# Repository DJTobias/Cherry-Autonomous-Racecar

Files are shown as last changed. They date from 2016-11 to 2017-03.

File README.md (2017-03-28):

# Cherry Autonomous Racecar (CAR) <br/>NCAT ECE Senior Design Project

## [Article on JetsonHacks](http://www.jetsonhacks.com/2017/03/02/daniel-tobias-car-cherry-autonomous-racecar/)

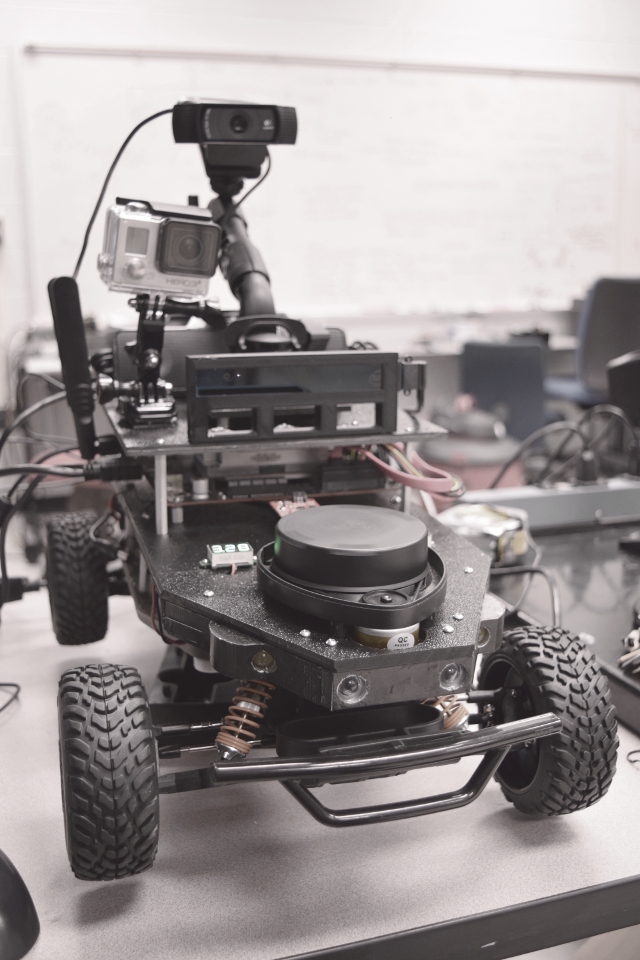
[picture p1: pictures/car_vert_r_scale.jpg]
Front view Front View CAR

<br/>

### Trial run
Trial run CAR (https://youtu.be/x3ub8OhKxhM)
<br/>

### Tear down
Tear down of CAR (https://youtu.be/HHdqdwMvcN8)
## [Hardware Schematic](/hardware/CAR_hardware_design.pdf)

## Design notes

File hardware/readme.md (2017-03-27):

# Bill of Materials
## https://goo.gl/QgxjAT
# Circuit Design
## [Teensy ESC & steering servo design](/pictures/CAR_Teensy_ESC_Steering_1Board_bb.png)
## [Neato-XV11 LIDAR power design](/pictures/Neato_Lidar_Circuit_bb.png)

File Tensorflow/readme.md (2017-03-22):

### Tensorflow implementaion of the CNN from End to End Learning for Self-Driving Car
Sample Dataset
<br/>
https://drive.google.com/drive/folders/0Bx1XHaRXk3kSUGZuVnJfaWJiY2M?usp=sharing

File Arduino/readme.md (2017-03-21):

# Arduino code for the Teensy 3.6 microcontroller
## On host PC
### Setup Arduino 
https://www.arduino.cc/en/Guide/Linux
<br/>
https://www.arduino.cc/download_handler.php?f=/arduino-1.8.1-linux64.tar.xz
<br/>

### Setup Teensyduino 
https://www.pjrc.com/teensy/td_download.html
<br/>
Save the text in the link below as a file named "49-teensy.rules"
<br/>
https://www.pjrc.com/teensy/49-teensy.rules
<br/>
sudo cp 49-teensy.rules /etc/udev/rules.d/

### Install ROS Kinetic packages and ros_lib
sudo apt-get install ros-kinetic-rosserial-arduino ros-kinetic-rosserial -y
<br/>
<br/>
**If there is a ros_lib in the arduino /sketchbook/libraries delete it**
<br/>
**Remake the ros_lib library**
<br/>
rosrun rosserial_arduino make_libraries.py ~/sketchbook/libraries
<br/>
<br/>
Find ArduinoHardware.h in ros_lib edit **line 44** to add support for Teensy 3.5 & 3.6
<br/>
\#if defined(\_\_MK20DX128\_\_) || defined(\_\_MK20DX256\_\_) || defined(\_\_MK64FX512\_\_) || defined(\_\_MK66FX1M0\_\_)
<br/>
https://github.com/ros-drivers/rosserial/blob/jade-devel/rosserial_arduino/src/ros_lib/ArduinoHardware.h

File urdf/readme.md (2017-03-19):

## Cherry Autonomous Racecar URDF

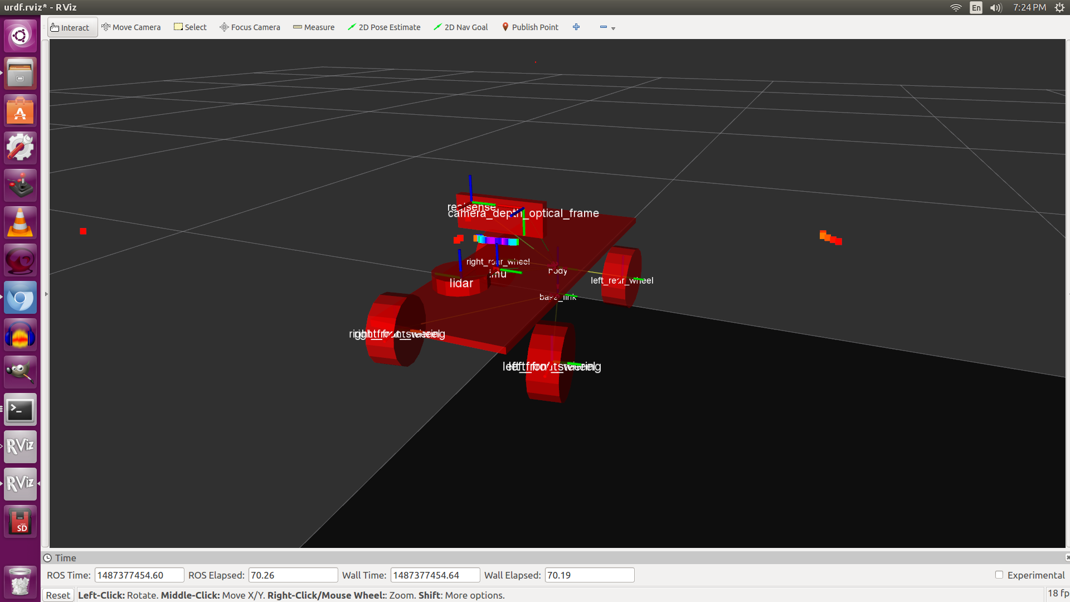
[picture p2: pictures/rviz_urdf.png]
Title


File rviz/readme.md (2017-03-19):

## Saved configuration for RVIZ to view CAR urdf and some sensors
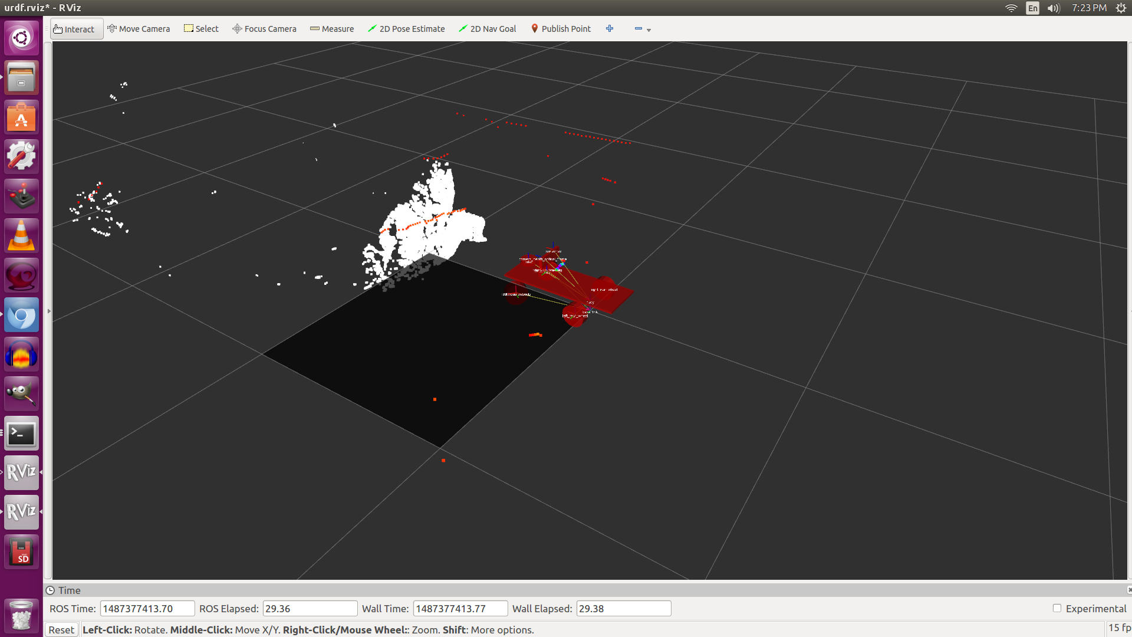
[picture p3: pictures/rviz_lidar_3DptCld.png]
Title


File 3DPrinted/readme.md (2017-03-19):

## 3D printed parts and platform schematics for the Cherry Autonomous Racecar

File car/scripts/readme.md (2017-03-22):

### Trained TF models should be place in this location

### You will have to make the folders for dataRecorder.py

cd
<br/>
mkdir DepthIMG
<br/>
mkdir TrainingIMG
<br/>
mkdir LidarIMG

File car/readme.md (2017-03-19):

## Cherry Autonomous Racecar(CAR) ROS package

### Sample trained model can be found here
https://drive.google.com/drive/folders/0Bx1XHaRXk3kSY1pfaW9hOVU4RWc
<br/>
Copy all three files into the scripts folder of the CAR ROS package
<br/>
### To start ROS Network
roslaunch car runCAR.launch
<br/>
### To start Neural Net
rosrun car runModel.py
___
## CAR controls for Xbox 360

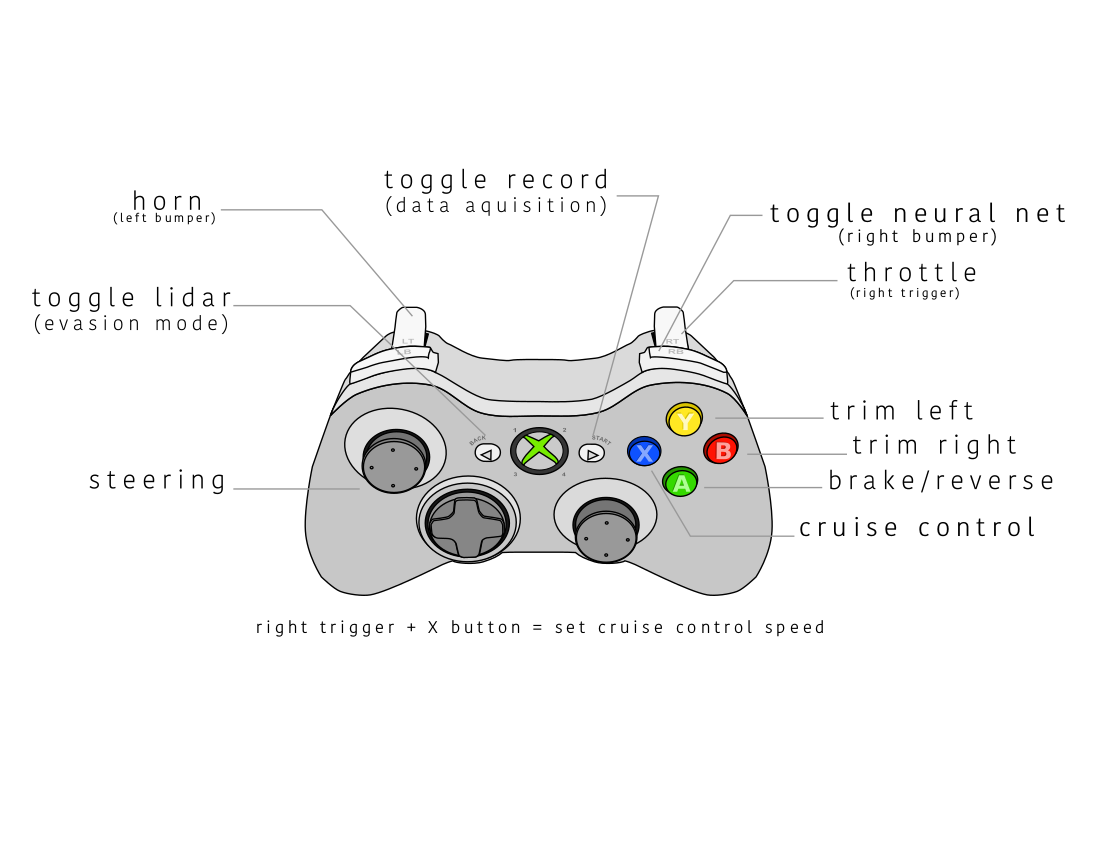
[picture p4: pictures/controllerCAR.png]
CAR Controller


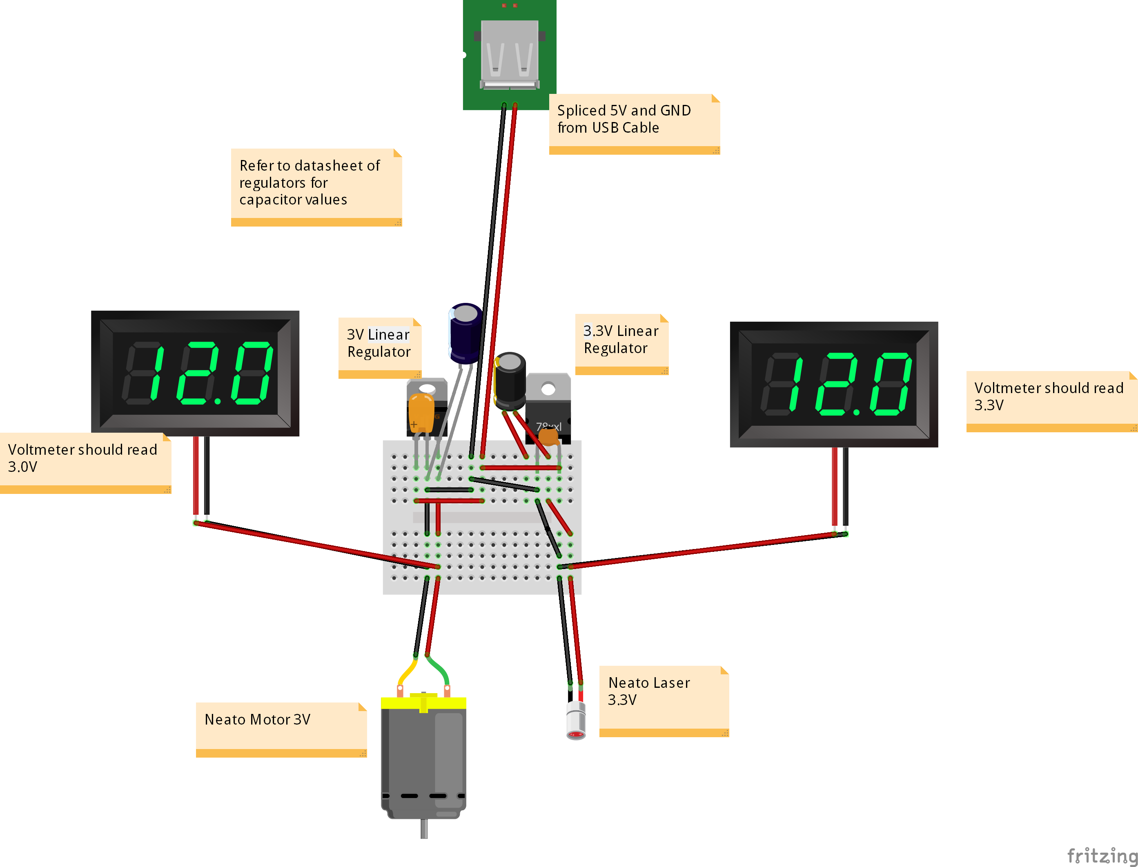
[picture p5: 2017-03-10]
pictures/Neato_Lidar_Circuit_bb.png

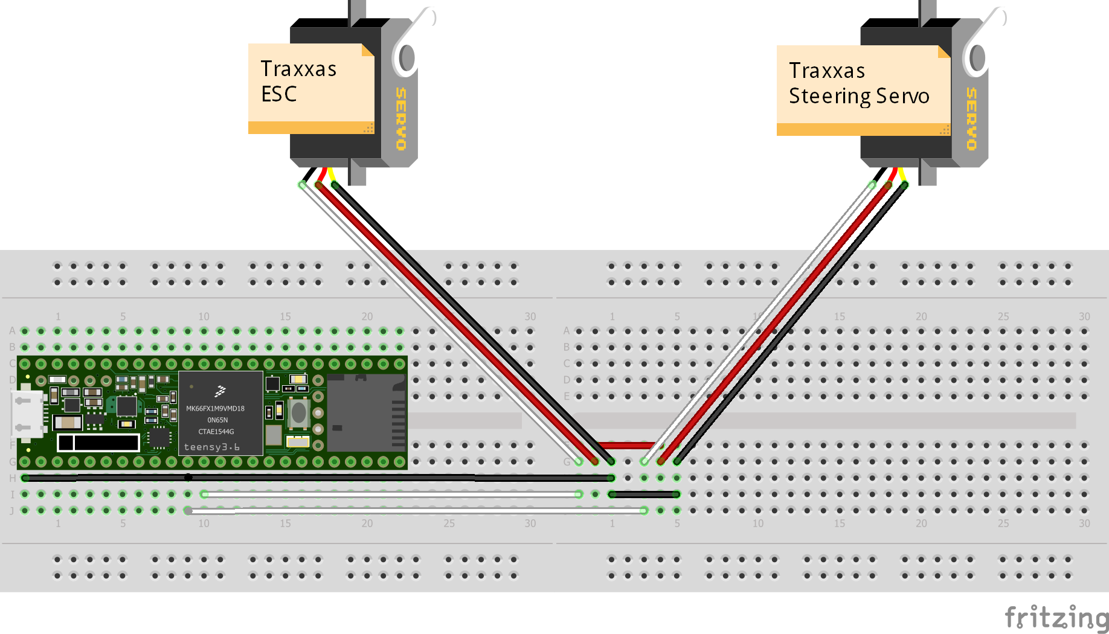
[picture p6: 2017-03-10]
pictures/CAR_Teensy_ESC_Steering_2Board_bb.png

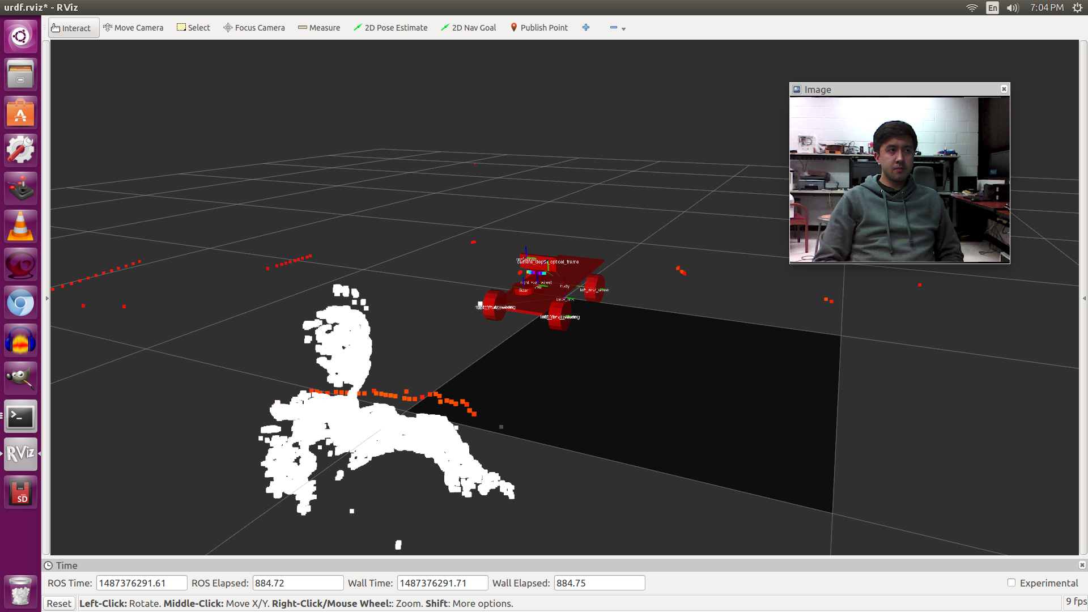
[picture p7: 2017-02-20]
pictures/rviz_lidar_3DptCld_RGB.png

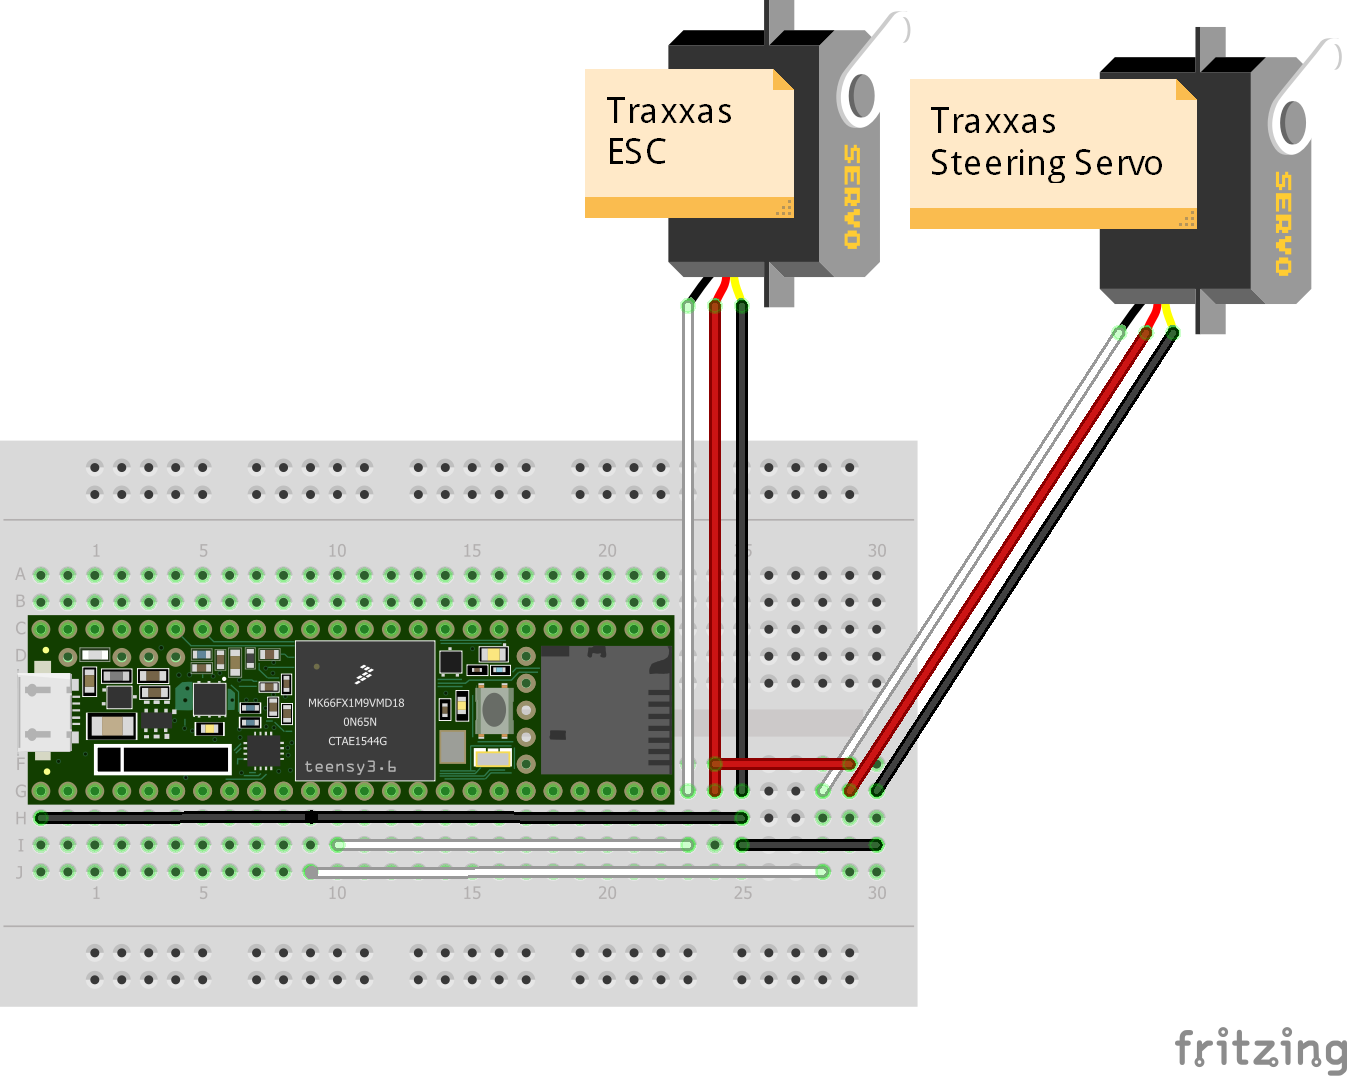
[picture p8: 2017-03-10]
pictures/CAR_Teensy_ESC_Steering_1Board_bb.png

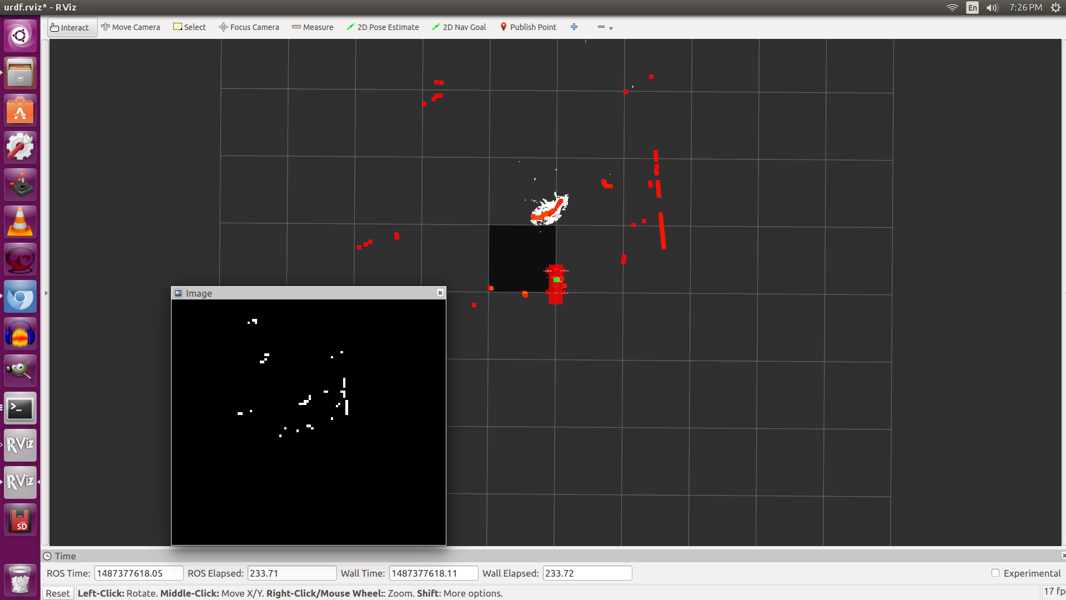
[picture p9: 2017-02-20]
pictures/rviz_lidar_lidargrid_img.png

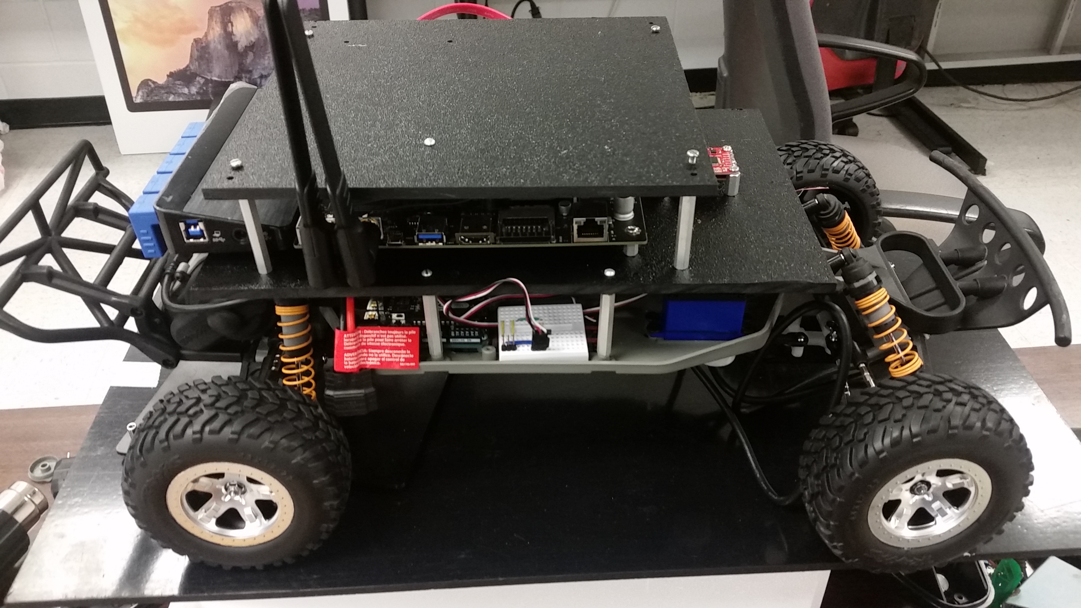
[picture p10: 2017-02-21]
pictures/car_prototype_august.jpg

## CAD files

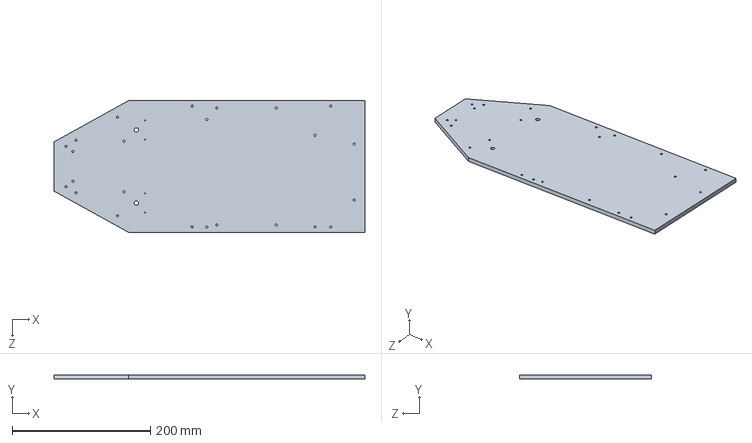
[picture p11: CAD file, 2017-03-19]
3DPrinted/car_main_platform.SLDPRT
449.3 x 6.35 x 190.5 mm

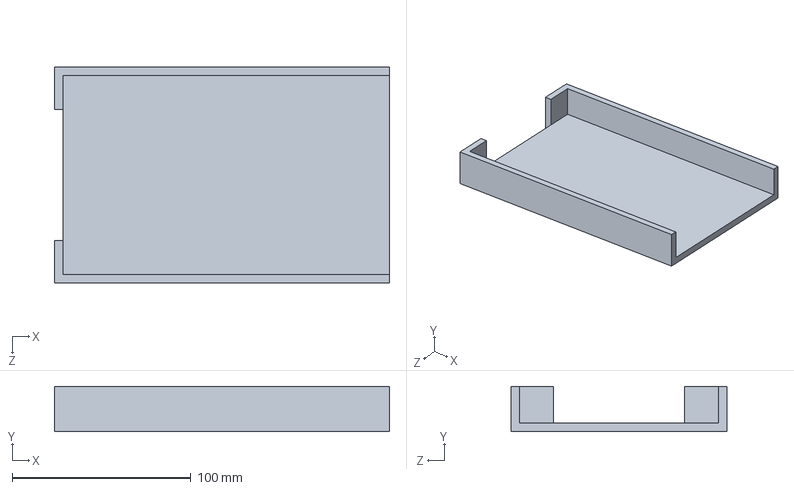
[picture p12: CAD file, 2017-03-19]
3DPrinted/car_XP18000_battery_holder.SLDPRT
187.3 x 25.4 x 120.7 mm

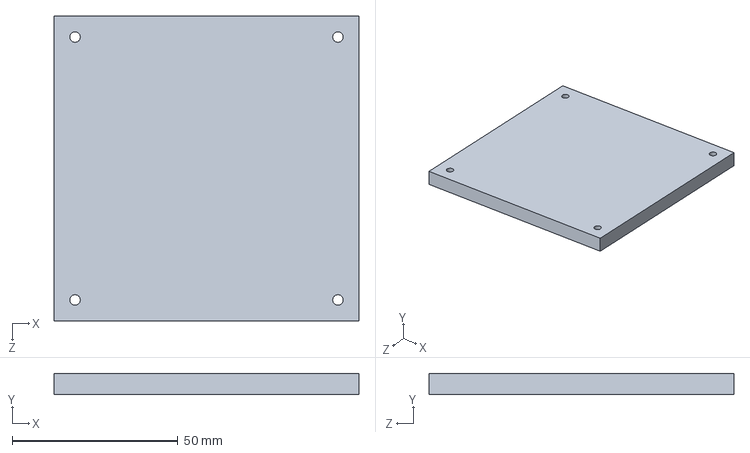
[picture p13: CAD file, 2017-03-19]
3DPrinted/car_webcam_panel.SLDPRT
92.0 x 6.35 x 92.0 mm

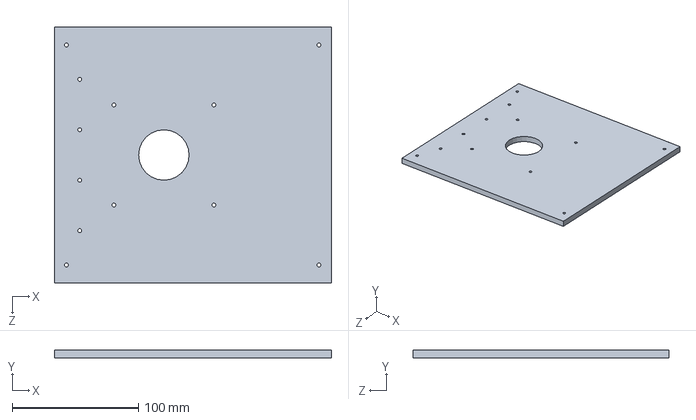
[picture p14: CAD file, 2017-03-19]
3DPrinted/car_top_panel.SLDPRT
219.7 x 6.35 x 203.2 mm

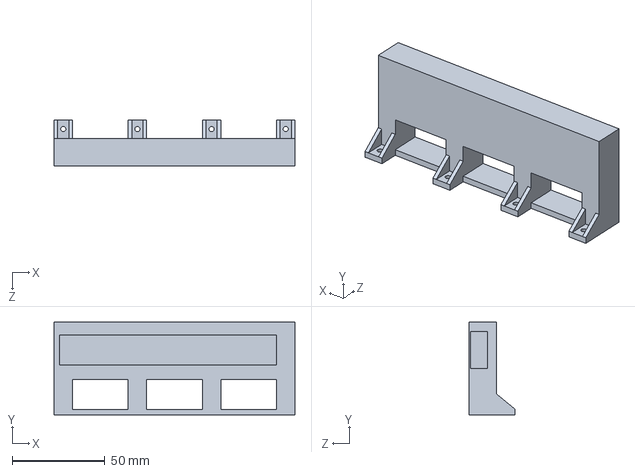
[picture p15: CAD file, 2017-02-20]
3DPrinted/car_RealSenseR200_mount.SLDPRT
130.0 x 50.0 x 25.0 mm

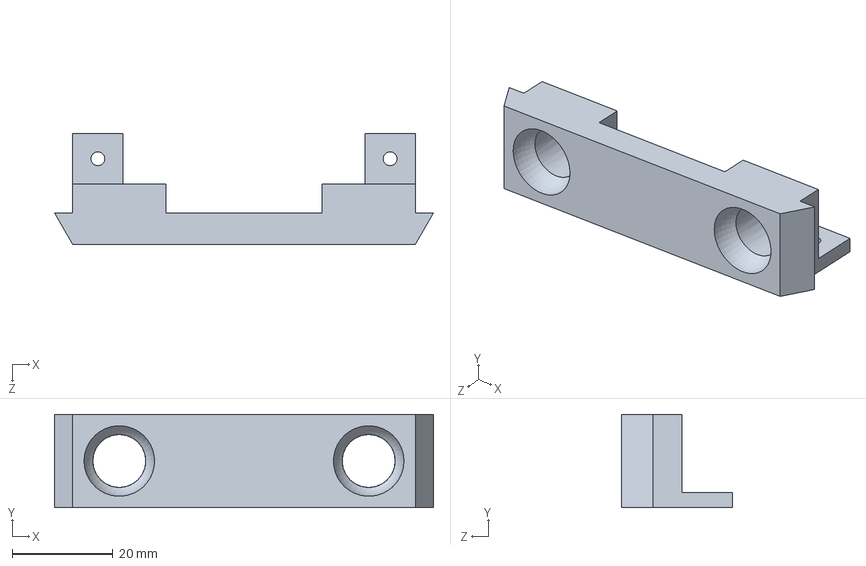
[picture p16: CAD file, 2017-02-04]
3DPrinted/car_front_headlights.SLDPRT
75.2 x 18.5 x 22.0 mm

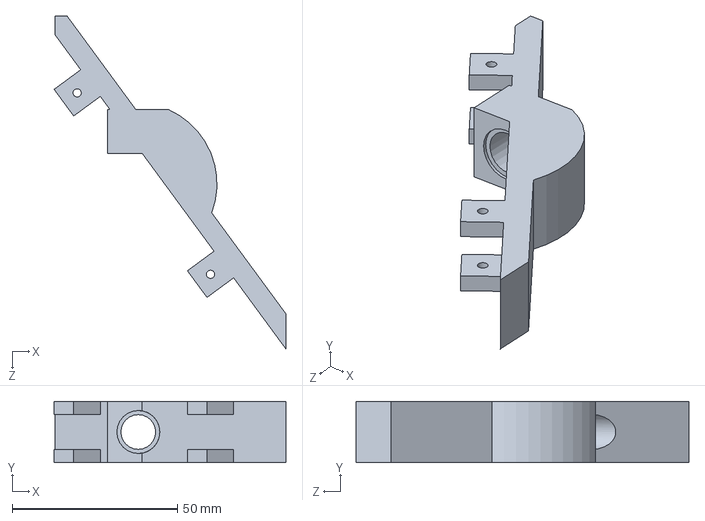
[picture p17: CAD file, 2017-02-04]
3DPrinted/car_side_turnsignal.SLDPRT
70.1 x 18.5 x 100.7 mm

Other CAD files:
3DPrinted/car_RealSenseR200_mount.STL
3DPrinted/car_XP18000_battery_holder.STL
3DPrinted/car_front_headlights.STL
3DPrinted/car_main_platform.STL
3DPrinted/car_side_turnsignal.STL
3DPrinted/car_top_panel.STL
3DPrinted/car_webcam_panel.STL

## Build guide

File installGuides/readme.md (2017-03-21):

## Install Order for Jetson TX1
1. Flash Jetpack on Jetson TX1
2. Preinstall script on Jetson TX1
3. installRealSenseR200 install to Jetson TX1
4. installJetPackSSD to install the filesystem on to the SSD
5. Preinstall script on SSD Jetpack
6. installRealSenseR200 install to SSD Jetpack (for safe measure)
7. installKernelModulesToSSD
8. installROS install to SSD Jetpack
9. Install CAR ROS package and dependencies
10. Follow steps in installRealSenseR200ROS install to SSD Jetpack
11. Follow steps in installXV_11  install to SSD Jetpack
12. Create swapspace from createSwap
13. Follow steps in installTensorFlowCUDA for SSD Jetpack
14. Follow steps in installTensorFlow for SSD Jetpack
15. (Optional) compile OpenCV 3.1 with CUDA and Gtreamer support from source
<br/>

## Install order Host PC
1. installROS_HOSTPC
2. installCUDA_cuDNN_HOSTPC
3. installTensorFlow_HOSTPC

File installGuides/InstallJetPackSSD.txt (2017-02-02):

###Tested with clean flash of Jetpack 2.2.1 on TX1
###Tested with Intel SSD 730
###Tested on 8/4/2016
###Tested with Tegra210_Linux_R24.1.0_armhf.tbz2
###Tested with Tegra_Linux_Sample-Root-Filesystem_R24.1.0_armhf.tbz2

##Tested on 1/14/2017 
##Tested with Samsung Evo 750 120GB SSD
##Tested with Tegra210_Linux_R24.2.1_aarch64.tbz2
##Tested with Tegra_Linux_Sample-Root-Filesystem_R24.2.1_aarch64.tbz2

###This process was done on a Lenovo Thinkpad with a ultrabay expansion for an extra SSD as seen here http://a.co/ctPOGup

###Done on HOST PC go to
https://developer.nvidia.com/embedded/linux-tegra
###download latest version .
download Jetson TX1 64-bit Driver Package
download 64-bit Sample Root Filesystem
move both to home directory.

###Extracts files and moves the sample filesystem to rootfs keeps permissions.  Do not use GUI extract

sudo tar -vxjf TegraXXX_Linux_RXX.X.X_armhf.tbz2
cd Linux_for_Tegra/rootfs
sudo tar jxpf ../../Tegra_Linux_Sample-Root-Filesystem_RXX.X.X_armhf.tbz2

###Run the apply_binaries.sh script to copy the NVIDIA libraries into rootfs directory.

cd ..
sudo ./apply_binaries.sh

###Format target storage to ext4 and mount it.
###use lsblk to make sure you are formatting the correct drive in my case only two storage devices are present on host

sudo mkfs.ext4 /dev/sdb
sudo mkdir /mnt/jetson
sudo mount /dev/sd? /mnt/jetson

###Copy Sample file system to target storage and unmount it.

cd Linux_for_Tegra/rootfs
sudo cp -a * /mnt/jetson && sync
sudo umount /mnt/jetson

###Turn on JetsonTX1 with previous clean installation of jetpack.
###Tested with clean install of Jetpack 2.2.1

sudo nautilus

###navigate to /boot/extlinux
###locate extlinux.conf
###open with gedit
###locate argument "root=/dev/mmcblk0p1" or something similar to this near the end
###change to "root=/dev/sda"  
###sda assumes that there are no other partitions on the SSD
###save file

###I deleted the ~extlinux.conf generated by gedit for safe measure
###it can be found by using the ls command in /boot/extlinux directory
sudo rm extlinux.conf~
###Turn off TX1

sudo shutdown -h now

###Make sure that there are no other storage devices except the SSD connected
###Turn on TX1 it should boot as SSD as home and show the internal eMMC as a SDCard on the unity launcher

###Steps derived from
http://demotomohiro.github.io/hardware/jetson_tk1/setup/nvidia_kernel.html
http://demotomohiro.github.io/hardware/jetson_tk1/setup/external_storage.html
https://devtalk.nvidia.com/default/topic/794002/-solved-l4t21-1-problem-booting-from-sata/#4386318

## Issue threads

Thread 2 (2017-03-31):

How to set up Teeny on Jetson TX1

dat-ai, 2017-03-31:
Dear Tobias,

I wonder how you could install Teensy on Jetson TX1. I am trying to do the same, however, Teensy 3.2 does not support AARCH 64 architecture yet..

Thanks!!

VisualMicro, 2017-03-31:
I think you install Teensy software on the Teensy then both the gpu and the teensy communicate using Serial tx/rx

dat-ai, 2017-03-31:
Good point. Thank you @VisualMacro! I will look into this option.

I previously set up Teensy communicate via a USB port

DJTobias, 2017-03-31:
Hey Dat,

A while back I could never get the Arduino IDE to work on the Jetson TX1, so I decided to upload the .ino files from the host computer instead.

dat-ai, 2017-03-31:
Thanks Tobias. I wrote my Teensy code on a Window machine, too.

However, my issue is that the Jetson TX1 does not recognize Teensy as `/dev/ttyACM*` or `/dev/ttyUSB*`  when I plug it in.

Did you install any extra packages or drivers for Teensy to work on TX1

DJTobias, 2017-03-31:
I see,

I don't think I install anything else to get it to work, maybe try this on the TX1
https://www.arduino.cc/en/Guide/Linux#toc6

Try attaching a regular Arduino to see if can recognize it.
It also might be a USB hub issue I am not sure what you are using.

I am assuming you can see the board on your host computer which is windows based from your post above, but have you tried it on a version of Ubuntu on your host to see if it can read the port?

dat-ai, 2017-03-31:
Finally, it worked!

The issue is because someone disabled `CONFIG_USB_ACM` kernel module on the NVIDIA Jetson( I actually used NVIDA Jetson TX2, Ubuntu 16.04, kernel-4-4.15)

Steps to resolve the issue:

1. Follow this tutorial: http://www.jetsonhacks.com/2017/03/25/build-kernel-and-modules-nvidia-jetson-tx2/
2. Before actually make kernel.  Run this command
```
sudo sed -i 's/.*CONFIG_USB_ACM.*/# CONFIG_USB_ACM=y/' /usr/src/kernel/kernel-4.4/.config
```
3. Follow the rest of the tutorial

At the end `dmesg` should show this when plugging in the Teensy
```
[  125.602321] usb 1-2.4: USB disconnect, device number 5
[  166.518422] usb 1-2.2: new full-speed USB device number 6 using xhci-tegra
[  166.627754] usb 1-2.2: New USB device found, idVendor=16c0, idProduct=0483
[  166.634715] usb 1-2.2: New USB device strings: Mfr=1, Product=2, SerialNumber=3
[  166.642213] usb 1-2.2: Product: USB Serial
[  166.646492] usb 1-2.2: Manufacturer: Teensyduino
[  166.651192] usb 1-2.2: SerialNumber: 2481500
**[  166.657388] cdc_acm 1-2.2:1.0: ttyACM0: USB ACM device**
```

Closed 2017-03-31.

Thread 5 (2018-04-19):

Training CNN

ArtlyStyles, 2018-04-19:
Could you please explain how to collect the steering angle and throttle during the manual driving for training? Is there special API supported by the hardware?

tevenfeng, 2018-08-31:
During the manual driving you have to use your joystick to control the car, and the joystick should be able to give you the steering angle and throttle could be obtained if you set a global maximum speed manually. That's how I get these parameters.

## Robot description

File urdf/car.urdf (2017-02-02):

<?xml version="1.0"?>
<robot name="car">

  <link name="base_link">
    <visual>
      <geometry>
        <box size =".001 .001 .001"/>
      </geometry>
      <origin rpy="0 0 0" xyz="0 0 0"/>
    </visual>
  </link>

  <joint name="base_link_to_right_front_steering" type="revolute">
    <parent link="base_link"/>
    <child link="right_front_steering"/>
    <origin xyz="0.326 -0.125 0.054"/>
    <axis xyz="0 0 1"/>
    <limit lower="-0.87" upper="0.87" effort="1000" velocity="1000"/>
  </joint>

  <link name="right_front_steering">
    <visual>
      <geometry>
        <box size =".001 .001 .001"/>
      </geometry>
      <origin rpy="0 0 0" xyz="0 0 0"/>
    </visual>
  </link>

  <joint name="right_front_steering_to_right_front_wheel" type="continuous">
    <parent link="right_front_steering"/>
    <child link="right_front_wheel"/>
    <origin xyz="0.0 0.0 0.0"/>
    <axis xyz="0 1 0"/>
  </joint>

  <link name="right_front_wheel">
    <visual>
      <geometry>
        <cylinder length ="0.043" radius="0.054"/>
      </geometry>
      <origin rpy="1.57075 0 0" xyz="0 0 0"/>
    </visual>
  </link>

  <joint name="base_link_to_left_front_steering" type="revolute">
    <parent link="base_link"/>
    <child link="left_front_steering"/>
    <origin xyz="0.326 0.125 0.054"/>
    <axis xyz="0 0 1"/>
    <limit lower="-0.87" upper="0.87" effort="1000" velocity="1000"/>
  </joint>

  <link name="left_front_steering">
    <visual>
      <geometry>
        <box size =".001 .001 .001"/>
      </geometry>
      <origin rpy="0 0 0" xyz="0 0 0"/>
    </visual>
  </link>

  <joint name="left_front_steering_to_left_front_wheel" type="continuous">
    <parent link="left_front_steering"/>
    <child link="left_front_wheel"/>
    <origin xyz="0.0 0.0 0.0"/>
    <axis xyz="0 1 0"/>
  </joint>

  <link name="left_front_wheel">
    <visual>
      <geometry>
        <cylinder length ="0.043" radius="0.054"/>
      </geometry>
      <origin rpy="1.57075 0 0" xyz="0 0 0"/>
    </visual>
  </link>

  <joint name="base_link_to_body" type="revolute">
    <parent link="base_link"/>
    <child link="body"/>
    <origin xyz="0 0 0.054"/>
    <axis xyz="0 1 0"/>
    <limit lower="-0.065" upper="0.065" effort="1000" velocity="1000"/>
  </joint>

  <link name="body">
    <visual>
      <geometry>
        <box size ="0.58 0.2 0.01"/>
      </geometry>
      <origin rpy="0 0 0" xyz="0.12 0 0.054"/>
    </visual>
  </link>

  <joint name="body_to_right_rear_wheel" type="continuous">
    <parent link="body"/>
    <child link="right_rear_wheel"/>
    <origin xyz="0 -0.125 0.0"/>
    <axis xyz="0 1 0"/>
  </joint>

  <link name="right_rear_wheel">
    <visual>
      <geometry>
        <cylinder length ="0.043" radius="0.054"/>
      </geometry>
      <origin rpy="1.57075 0 0" xyz="0 0 0"/>
    </visual>
  </link>

  <joint name="body_to_left_rear_wheel" type="continuous">
    <parent link="body"/>
    <child link="left_rear_wheel"/>
    <origin xyz="0 0.125 0.0"/>
    <axis xyz="0 1 0"/>
  </joint>

  <link name="left_rear_wheel">
    <visual>
      <geometry>
        <cylinder length ="0.043" radius="0.054"/>
      </geometry>
      <origin rpy="1.57075 0 0" xyz="0 0 0"/>
    </visual>
  </link>

  <joint name="body_to_imu" type="fixed">
    <parent link="body"/>
    <child link="imu"/>
    <origin xyz="0.236 0 0.082"/>
  </joint>

  <link name="imu">
    <visual>
      <geometry>
        <box size =".01 .01 .01"/>
      </geometry>
      <origin rpy="0 0 0" xyz="0 0 0"/>
    </visual>
  </link>

  <joint name="body_to_lidar" type="fixed">
    <parent link="body"/>
    <child link="lidar"/>
    <origin xyz="0.339 0 0.107" rpy="0 0 3.1415926"/>
  </joint>

  <link name="lidar">
    <visual>
      <geometry>
        <cylinder length ="0.020" radius="0.039"/>
      </geometry>
      <origin rpy="0 0 0" xyz="0 0 0"/>
    </visual>
  </link>

  <joint name="body_to_realsense" type="fixed">
    <parent link="body"/>
    <child link="realsense"/>
    <origin xyz="0.226 -0.044 0.177"/>
  </joint>
 <!--   <origin xyz="0.226 -0.044 0.177"/>-->
  <link name="realsense">
    <visual>
      <geometry>
        <box size ="0.015 0.139 0.051"/>
      </geometry>
      <origin rpy="0 0 0" xyz="-0.0075 0.044 -0.016"/>
    </visual>
  </link>

  <joint name="body_to_camera_depth_optical_frame" type="revolute">
    <parent link="body"/>
    <child link="camera_depth_optical_frame"/>
    <origin xyz="0.226 0.04 0.177" rpy="-1.57079 0 -1.57079"/>
    <axis xyz="0 0 1"/>
    <limit lower="-0.001" upper="0.001" effort="1000" velocity="1000"/>
  </joint>

  <!-- rpy="-1.57079 1.57079 0" -->

  <link name="camera_depth_optical_frame">
    <visual>
      <geometry>
        <box size =".001 .001 .001"/>
      </geometry>
      <origin rpy="0 0 0" xyz="0 0 0"/>
    </visual>
  </link>

</robot>

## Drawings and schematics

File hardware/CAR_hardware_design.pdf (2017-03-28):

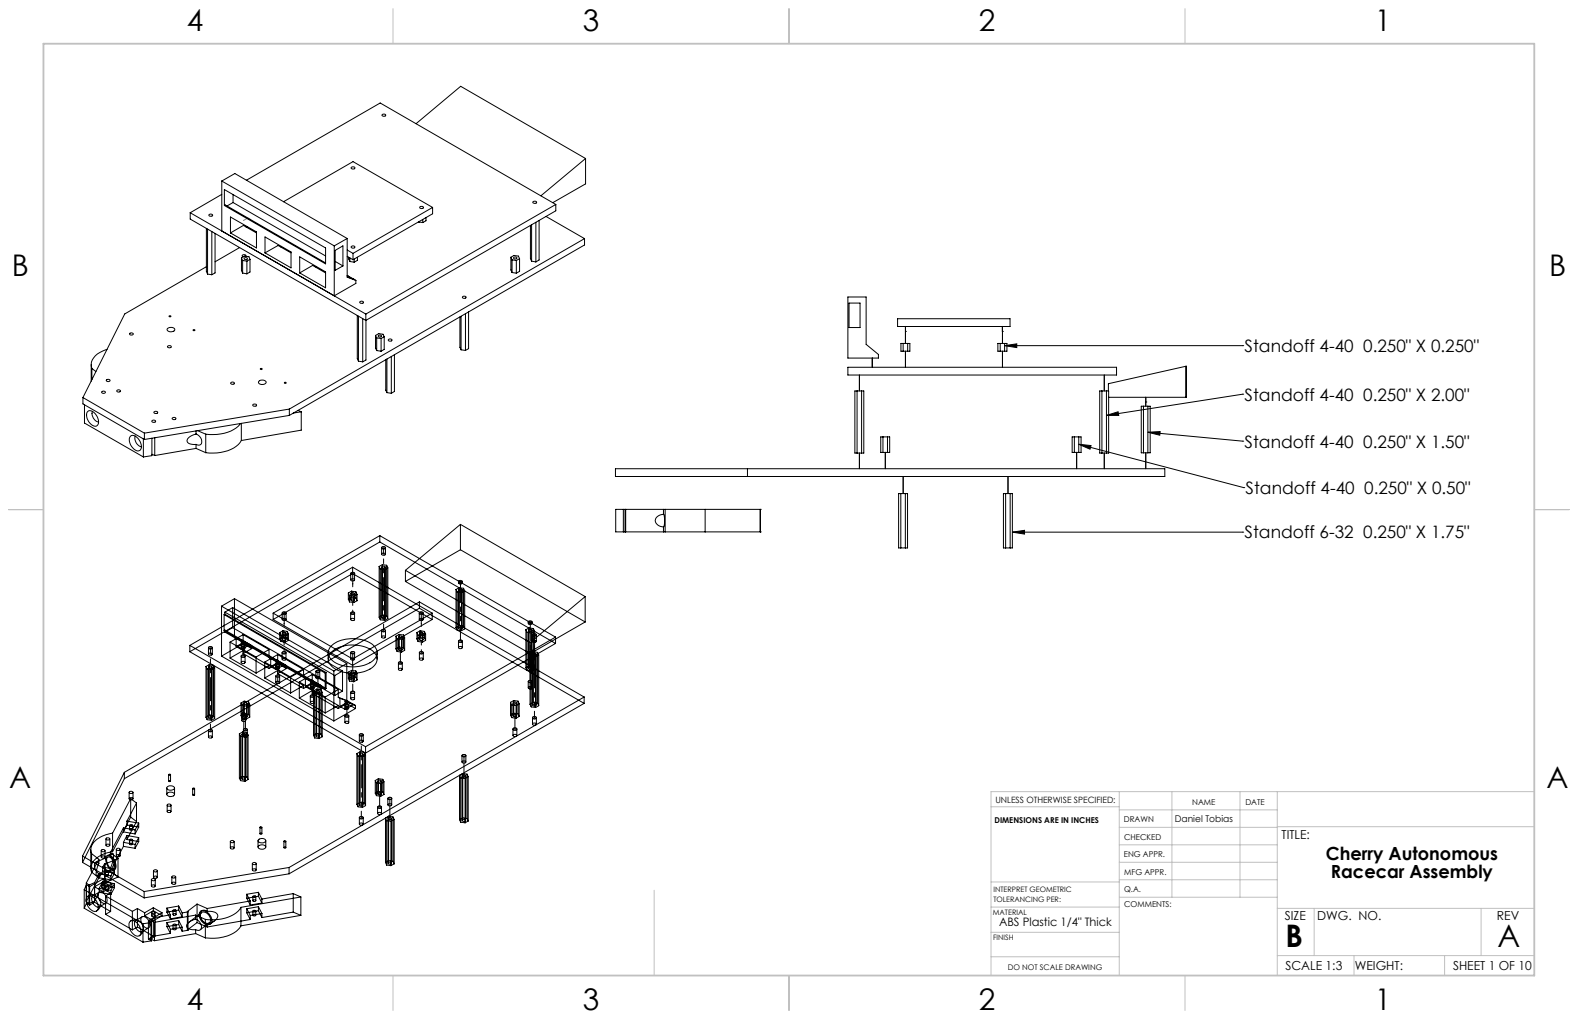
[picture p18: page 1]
Standoff 4-40 0.250" X 1.50"; Standoff 4-40 0.250" X 2.00"; Standoff 4-40 0.250" X 0.250"; Standoff 4-40 0.250" X 0.50"; Standoff 6-32 0.250" X 1.75"; DO NOT SCALE DRAWING; SHEET 1 OF 10; SCALE 1:3; WEIGHT:; DWG. NO.; REV

UNLESS OTHERWISE SPECIFIED: | | NAME | DATE
DIMENSIONS ARE IN INCHES | DRAWN | Daniel Tobias

CHECKED | | | TITLE: Cherry Autonomous Racecar Assembly

ENG APPR.
MFG APPR.

INTERPRET GEOMETRIC TOLERANCING PER: | Q.A.

MATERIAL
ABS Plastic 1/4" Thick
FINISH

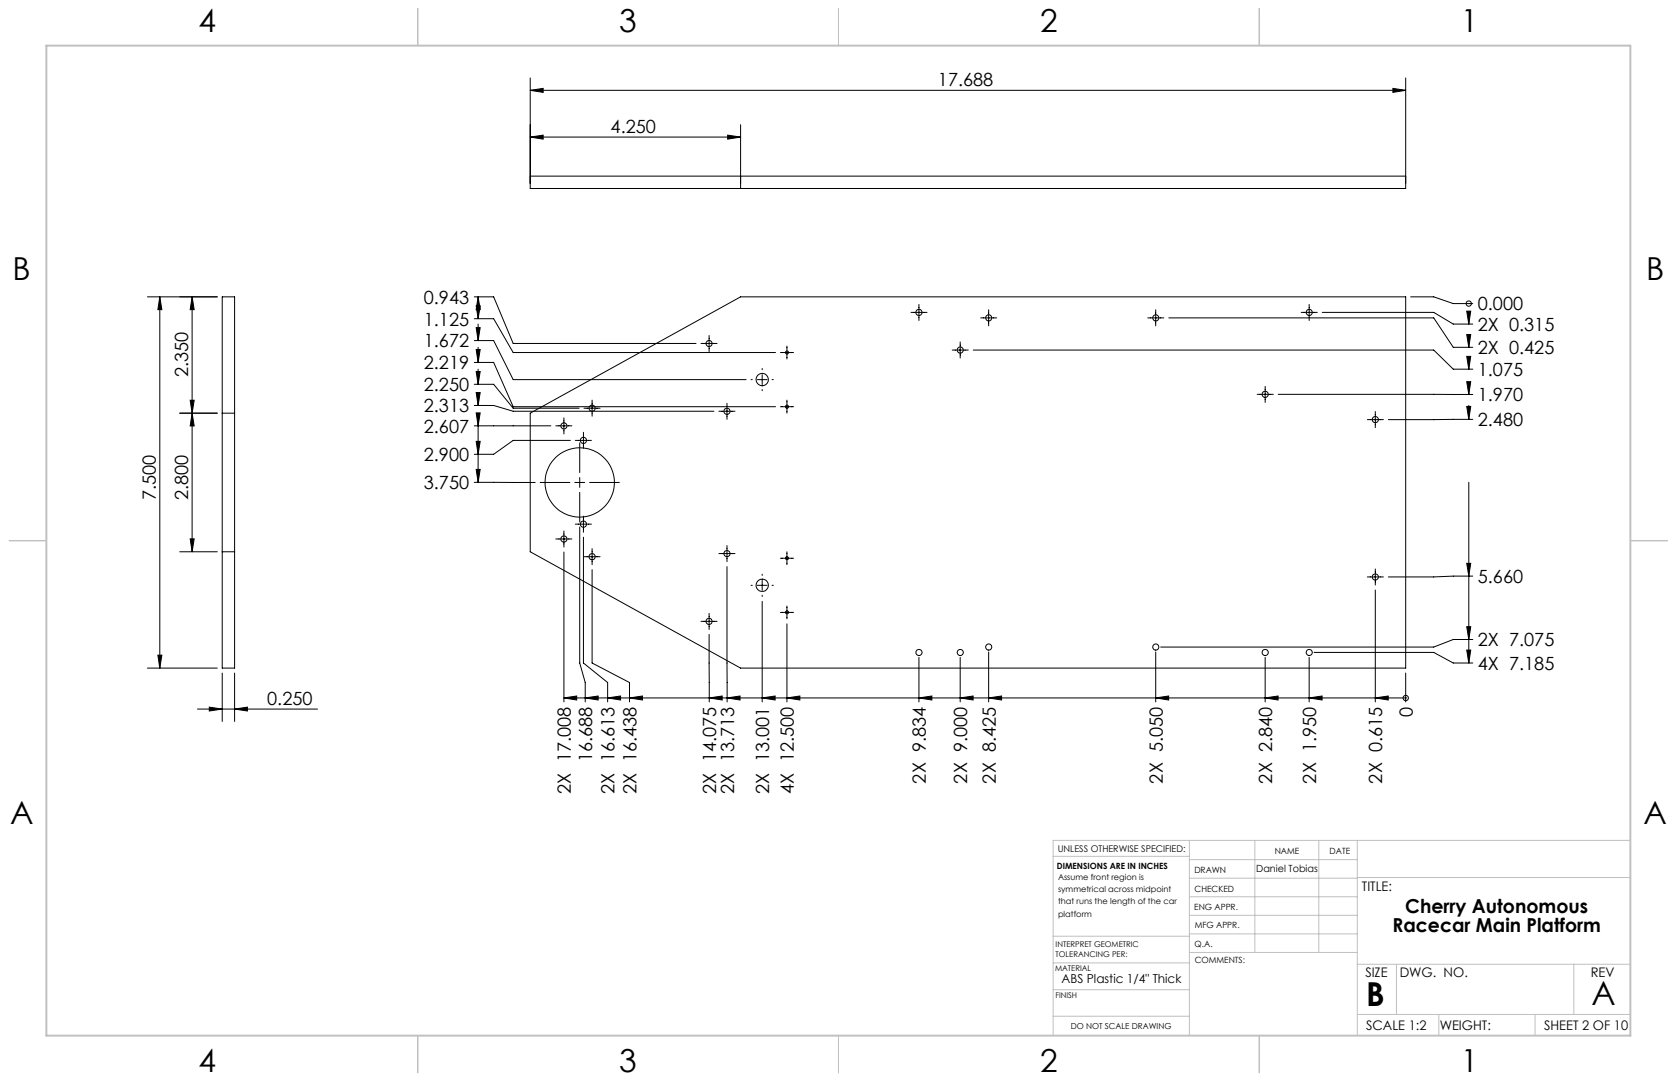
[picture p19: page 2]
SCALE 1:2; WEIGHT:; DWG. NO.; REV

UNLESS OTHERWISE SPECIFIED: | | NAME | DATE
DIMENSIONS ARE IN INCHES Assume front region is symmetrical across midpoint that runs the length of the car platform | DRAWN | Daniel Tobias

CHECKED | | | TITLE: Cherry Autonomous Racecar Main PlatformA

ENG APPR.
MFG APPR.

INTERPRET GEOMETRIC TOLERANCING PER: | Q.A.

MATERIAL
ABS Plastic 1/4" Thick

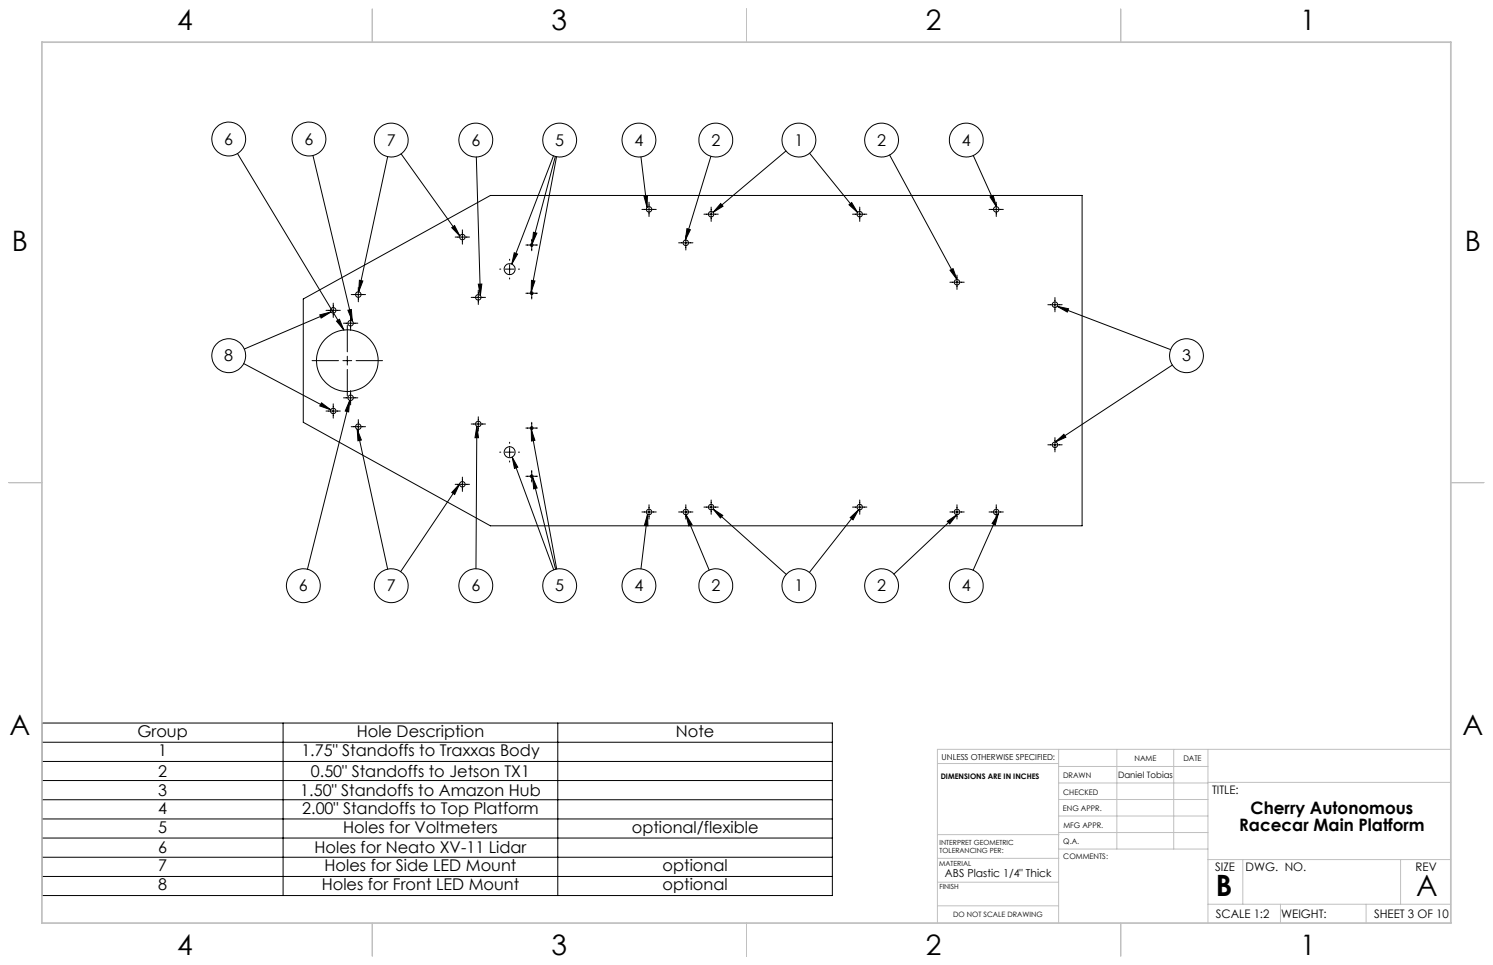
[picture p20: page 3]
0.50" Standoffs to Jetson TX1; 1.50" Standoffs to Amazon Hub; 2.00" Standoffs to Top Platform; Holes for Voltmeters; optional/flexible; Holes for Side LED Mount; optional; Holes for Front LED Mount; Daniel Tobias; SCALE 1:2; WEIGHT:; DWG. NO.; REV; MFG APPR.; ENG APPR.

Group | Hole Description | Note
1 | 1.75" Standoffs to Traxxas Body

UNLESS OTHERWISE SPECIFIED: | NAME | DATE

DIMENSIONS ARE IN INCHES

TITLE:
Cherry Autonomous
Racecar Main Platform

6 | Holes for Neato XV-11 Lidar

INTERPRET GEOMETRIC TOLERANCING PER: | Q.A.

MATERIAL
ABS Plastic 1/4" Thick

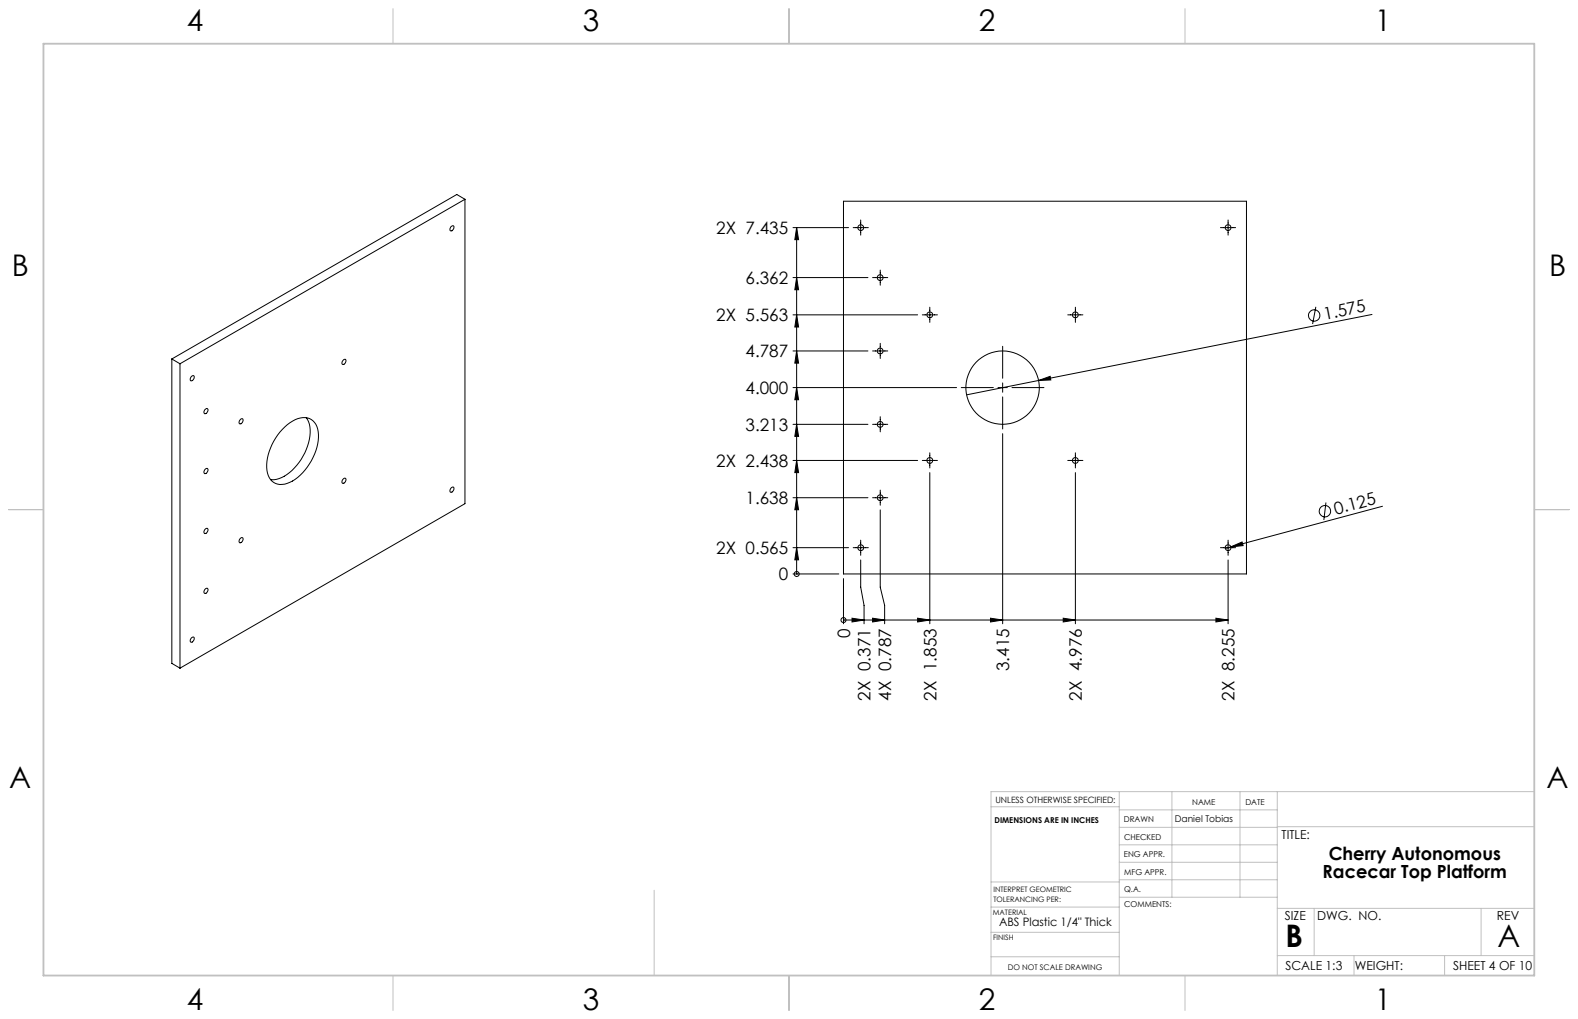
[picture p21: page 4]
SCALE 1:3; WEIGHT:; DWG. NO.; REV

UNLESS OTHERWISE SPECIFIED: | | NAME | DATE
DIMENSIONS ARE IN INCHES | DRAWN | Daniel Tobias

CHECKED | | | TITLE: Cherry Autonomous Racecar Top Platform

ENG APPR.
MFG APPR.

INTERPRET GEOMETRIC TOLERANCING PER: | Q.A.

MATERIAL
ABS Plastic 1/4" Thick

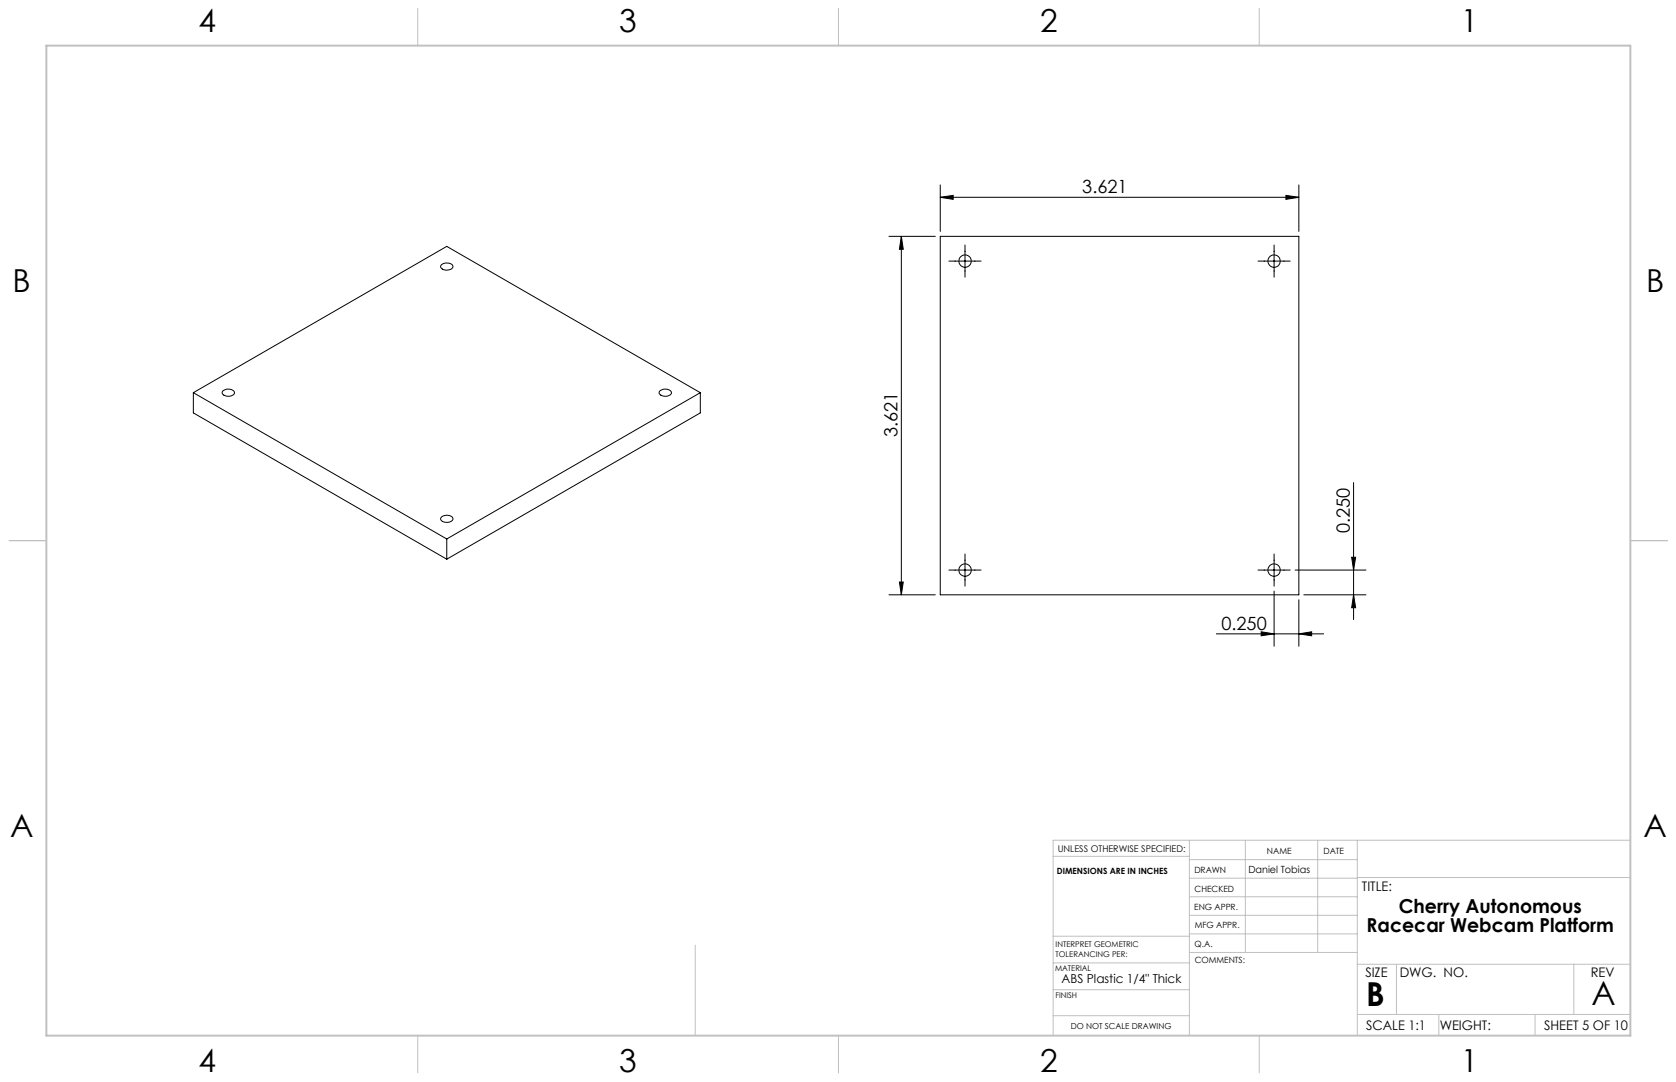
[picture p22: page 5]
SCALE 1:1; WEIGHT:; DWG. NO.; REV

UNLESS OTHERWISE SPECIFIED: | | NAME | DATE
DIMENSIONS ARE IN INCHES | DRAWN | Daniel Tobias

CHECKED | | | TITLE: Cherry Autonomous Racecar Webcam Platform

ENG APPR.
MFG APPR.

INTERPRET GEOMETRIC TOLERANCING PER: | Q.A.

MATERIAL
ABS Plastic 1/4" Thick

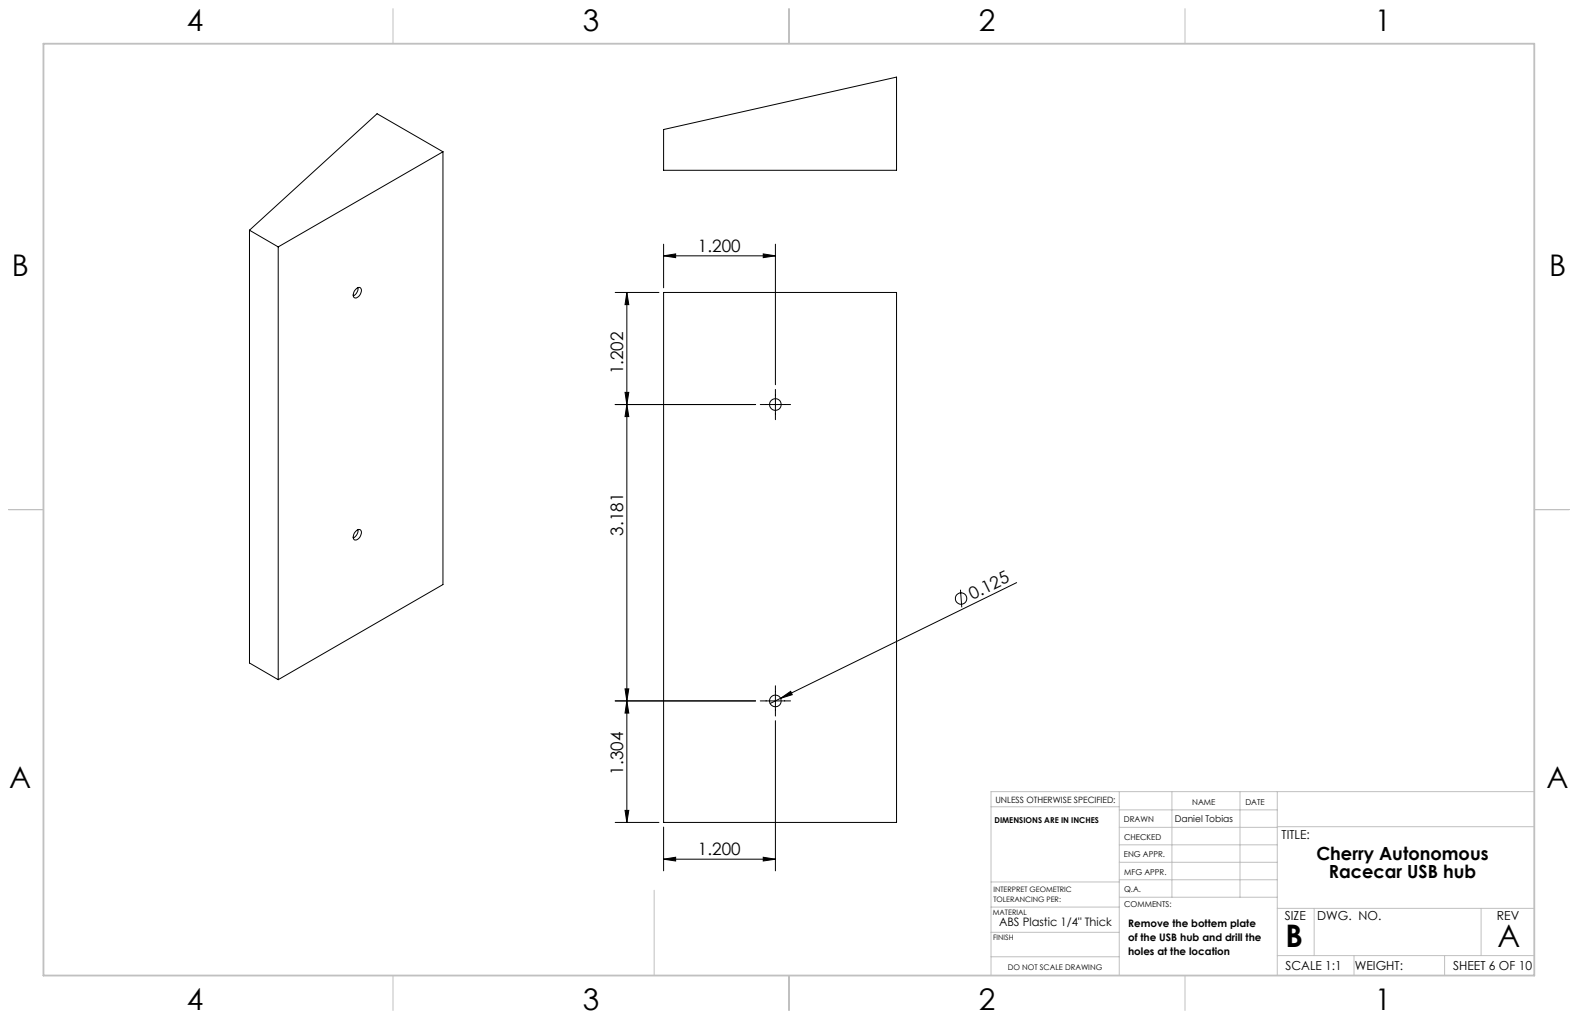
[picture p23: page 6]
DWG. NO.; REV

UNLESS OTHERWISE SPECIFIED: | | NAME | DATE
DIMENSIONS ARE IN INCHES | DRAWN | Daniel Tobias

CHECKED | | | TITLE: Cherry Autonomous Racecar USB hub

ENG APPR.
MFG APPR.

INTERPRET GEOMETRIC TOLERANCING PER: | Q.A.

COMMENTS:
Remove the bottem plate
of the USB hub and drill the
holes at the location

MATERIAL
ABS Plastic 1/4" Thick

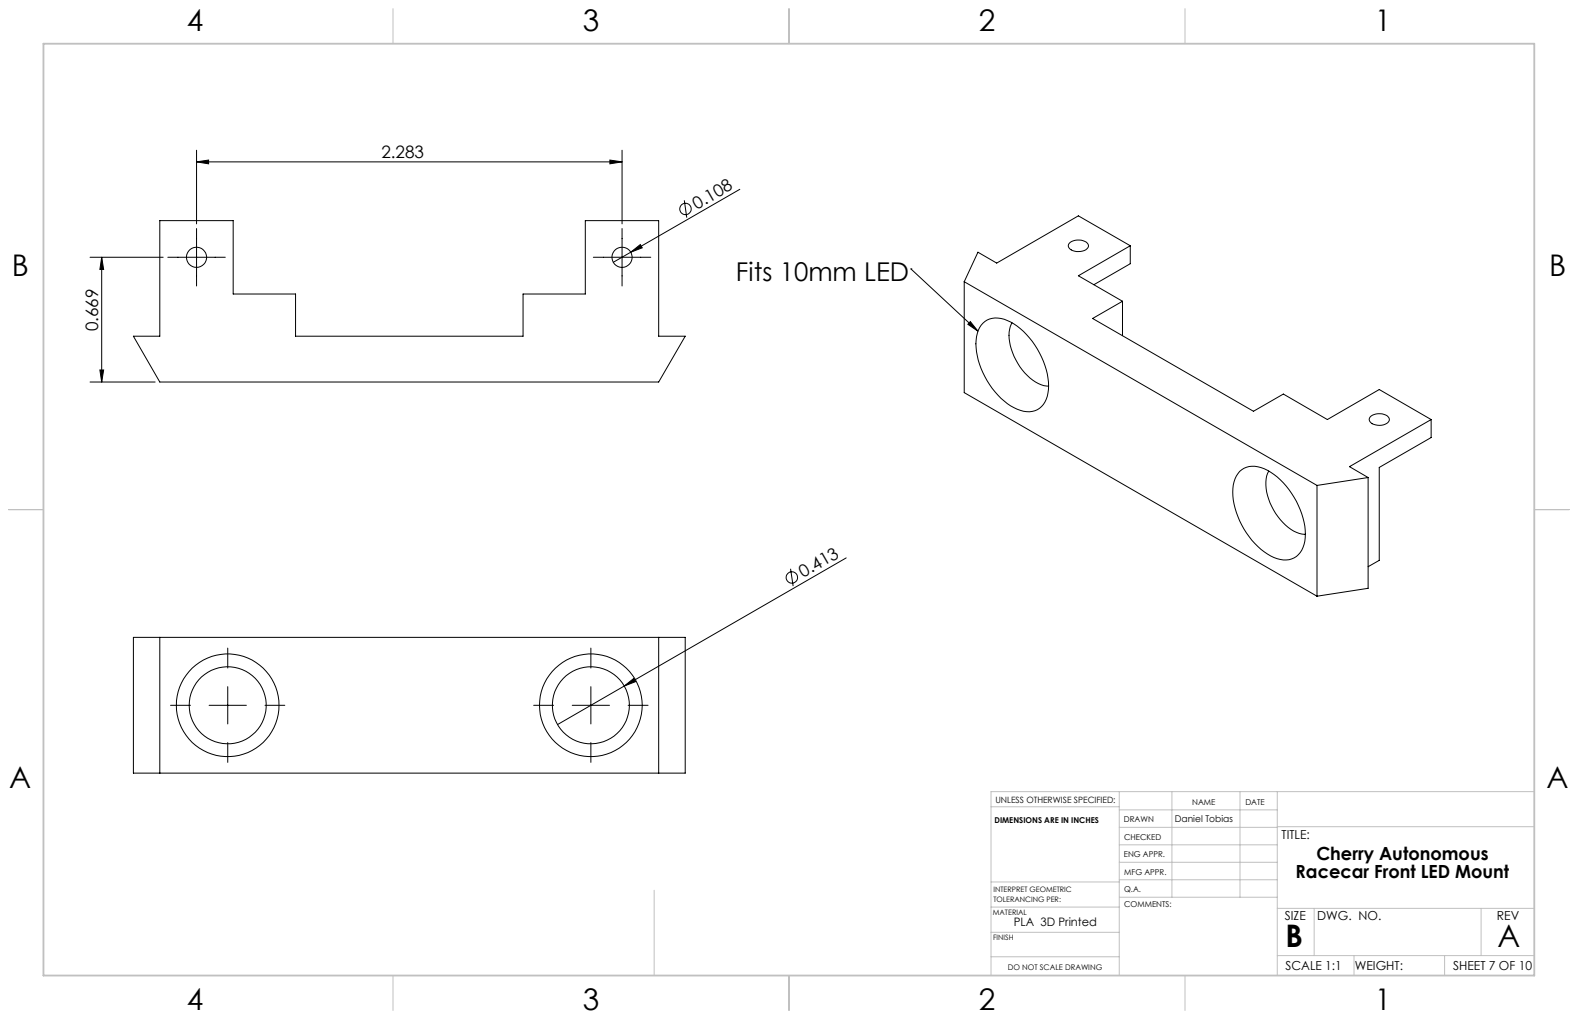
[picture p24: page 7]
Fits 10mm LED; PLA 3D Printed; DWG. NO.; REV

UNLESS OTHERWISE SPECIFIED: | | NAME | DATE
DIMENSIONS ARE IN INCHES | DRAWN | Daniel Tobias

CHECKED | | | TITLE: Cherry Autonomous Racecar Front LED Mount

ENG APPR.
MFG APPR.

INTERPRET GEOMETRIC TOLERANCING PER: | Q.A.

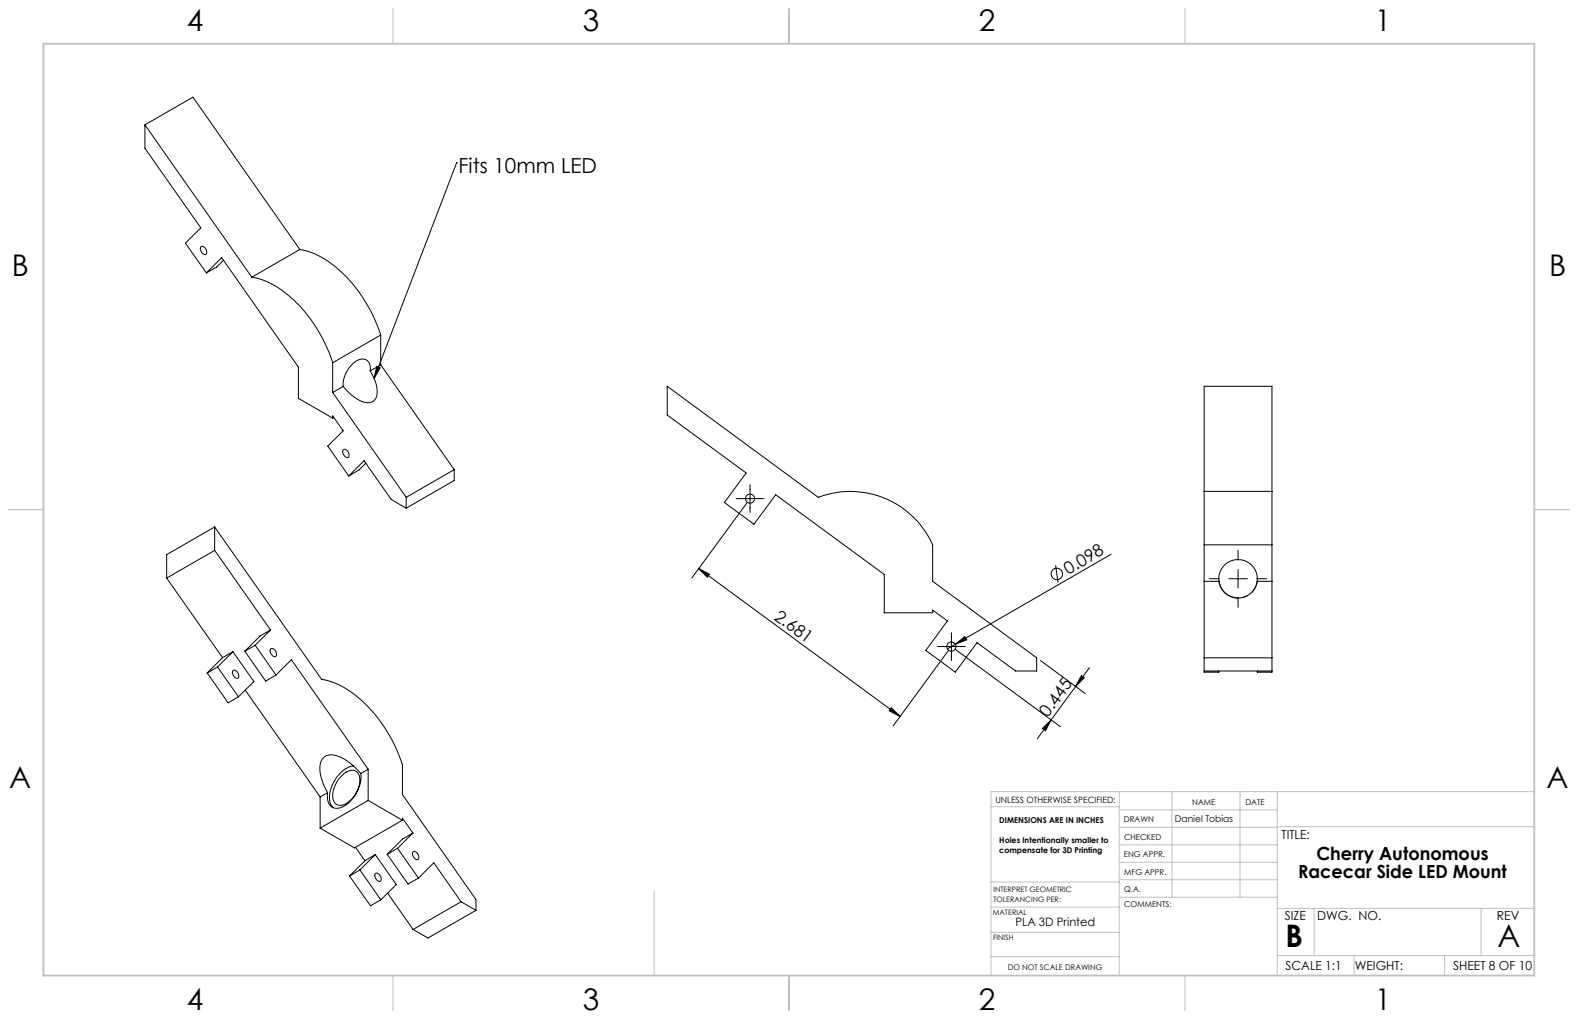
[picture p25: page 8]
Fits 10mm LED; PLA 3D Printed; DWG. NO.; REV

UNLESS OTHERWISE SPECIFIED: | | NAME | DATE
DIMENSIONS ARE IN INCHES Holes Intentionally smaller to compensate for 3D Printing | DRAWN | Daniel Tobias

CHECKED | | | TITLE: Cherry Autonomous Racecar Side LED Mount

ENG APPR.
MFG APPR.

INTERPRET GEOMETRIC TOLERANCING PER: | Q.A.

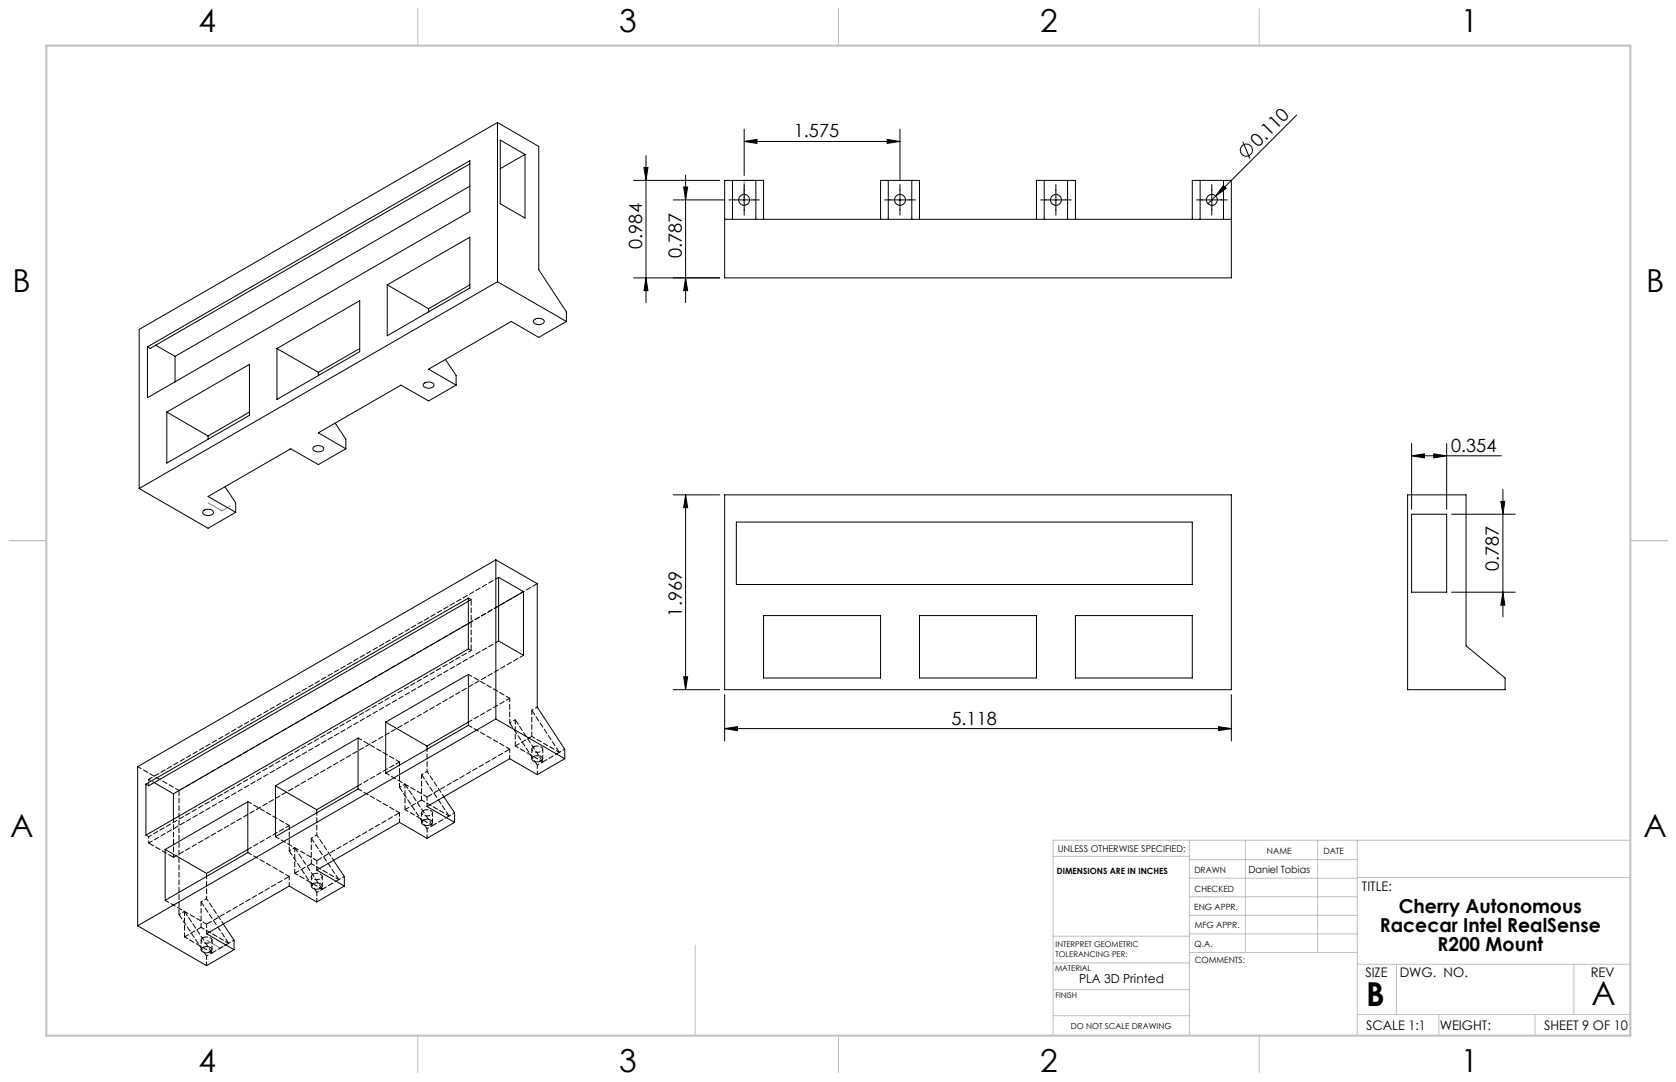
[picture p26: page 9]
PLA 3D Printed; DWG. NO.; REV

UNLESS OTHERWISE SPECIFIED: | | NAME | DATE
DIMENSIONS ARE IN INCHES | DRAWN | Daniel Tobias

CHECKED | | | TITLE: Cherry Autonomous Racecar Intel RealSense R200 Mount

ENG APPR.
MFG APPR.

INTERPRET GEOMETRIC TOLERANCING PER: | Q.A.

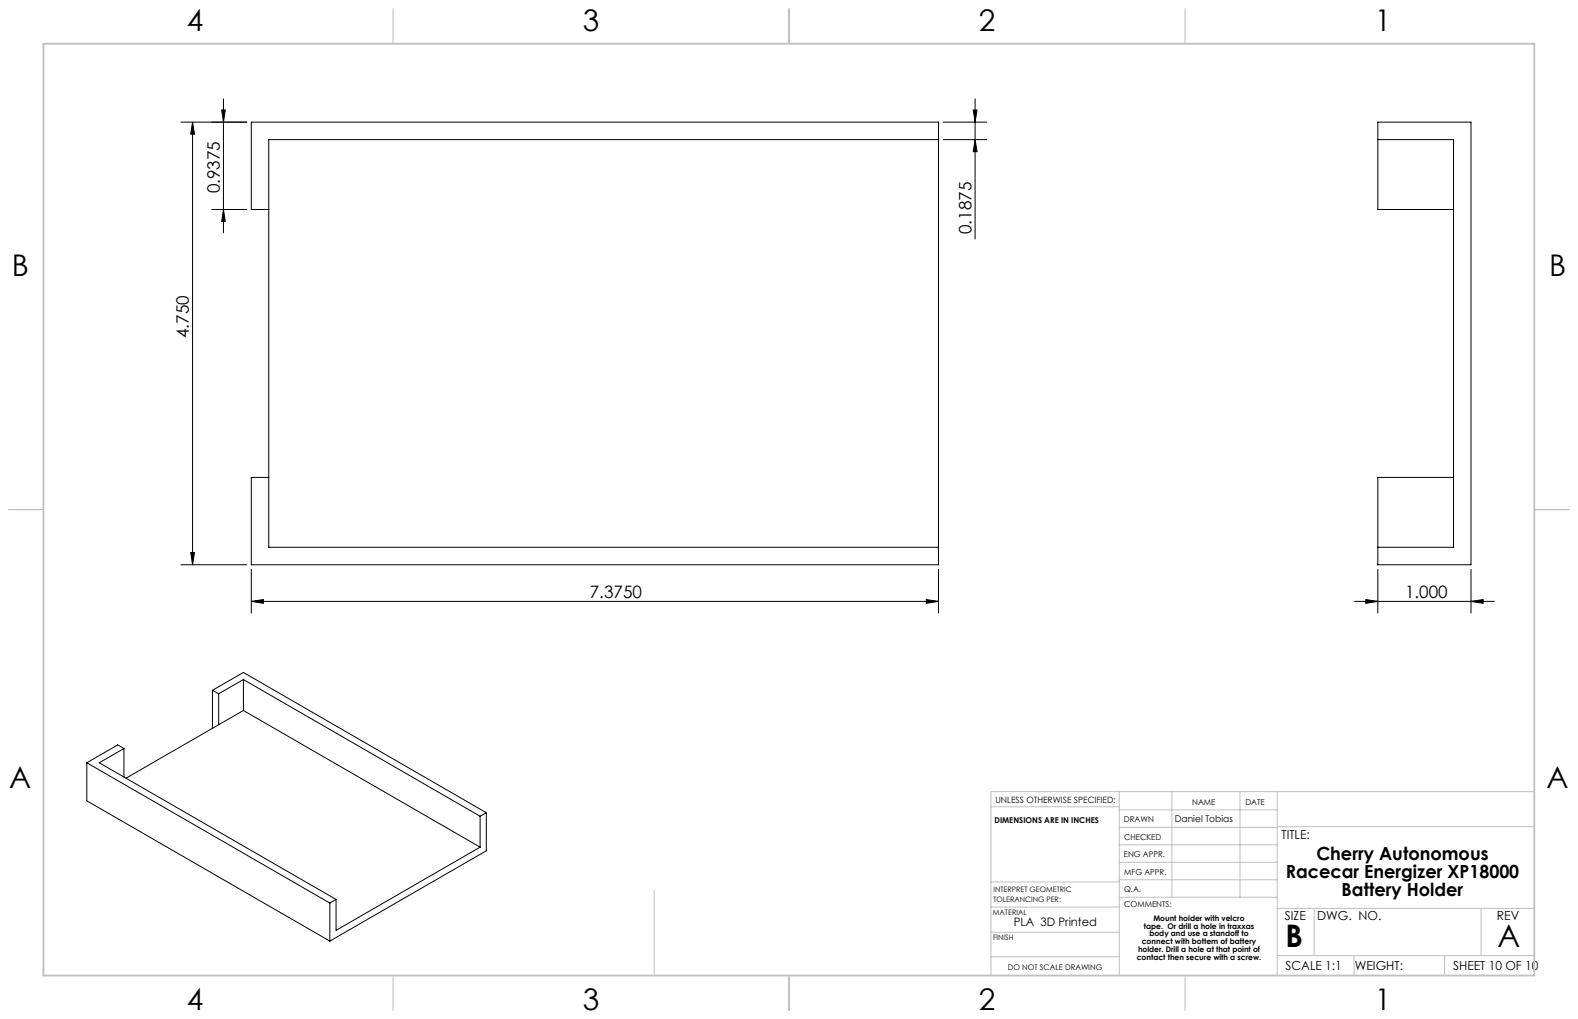
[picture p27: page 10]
PLA 3D Printed; DWG. NO.; REV

UNLESS OTHERWISE SPECIFIED: | | NAME | DATE
DIMENSIONS ARE IN INCHES | DRAWN | Daniel Tobias

CHECKED | | | TITLE: Cherry Autonomous Racecar Energizer XP18000 Battery Holder

ENG APPR.
MFG APPR.

INTERPRET GEOMETRIC TOLERANCING PER: | Q.A.

COMMENTS:
Mount holder with velcro

tape. Or drill a hole in traxxas
body and use a standoff to
connect with bottem of battery
holder. Drill a hole at that point of
contact then secure with a screw.

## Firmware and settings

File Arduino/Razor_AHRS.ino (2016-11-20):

/***************************************************************************************************************
* Razor AHRS Firmware v1.4.2.2
* 9 Degree of Measurement Attitude and Heading Reference System
* for Sparkfun "9DOF Razor IMU" (SEN-10125 and SEN-10736)
* and "9DOF Sensor Stick" (SEN-10183, 10321 and SEN-10724)
*
* Released under GNU GPL (General Public License) v3.0
* Copyright (C) 2013 Peter Bartz [http://ptrbrtz.net]
* Copyright (C) 2011-2012 Quality & Usability Lab, Deutsche Telekom Laboratories, TU Berlin
*
* Infos, updates, bug reports, contributions and feedback:
*     https://github.com/ptrbrtz/razor-9dof-ahrs
*
*
* History:
*   * Original code (http://code.google.com/p/sf9domahrs/) by Doug Weibel and Jose Julio,
*     based on ArduIMU v1.5 by Jordi Munoz and William Premerlani, Jose Julio and Doug Weibel. Thank you!
*
*   * Updated code (http://groups.google.com/group/sf_9dof_ahrs_update) by David Malik (david.zsolt.malik@gmail.com)
*     for new Sparkfun 9DOF Razor hardware (SEN-10125).
*
*   * Updated and extended by Peter Bartz (peter-bartz@gmx.de):
*     * v1.3.0
*       * Cleaned up, streamlined and restructured most of the code to make it more comprehensible.
*       * Added sensor calibration (improves precision and responsiveness a lot!).
*       * Added binary yaw/pitch/roll output.
*       * Added basic serial command interface to set output modes/calibrate sensors/synch stream/etc.
*       * Added support to synch automatically when using Rovering Networks Bluetooth modules (and compatible).
*       * Wrote new easier to use test program (using Processing).
*       * Added support for new version of "9DOF Razor IMU": SEN-10736.
*       --> The output of this code is not compatible with the older versions!
*       --> A Processing sketch to test the tracker is available.
*     * v1.3.1
*       * Initializing rotation matrix based on start-up sensor readings -> orientation OK right away.
*       * Adjusted gyro low-pass filter and output rate settings.
*     * v1.3.2
*       * Adapted code to work with new Arduino 1.0 (and older versions still).
*     * v1.3.3
*       * Improved synching.
*     * v1.4.0
*       * Added support for SparkFun "9DOF Sensor Stick" (versions SEN-10183, SEN-10321 and SEN-10724).
*     * v1.4.1
*       * Added output modes to read raw and/or calibrated sensor data in text or binary format.
*       * Added static magnetometer soft iron distortion compensation
*     * v1.4.2
*       * (No core firmware changes)
*     * v1.4.2.1
*       * New output mode to support ROS Imu use emits YPR + accel + rot. vel.
*     * v1.4.2.2
*       * New input mode to set calibration parameters
*
* TODOs:
*   * Allow optional use of EEPROM for storing and reading calibration values.
*   * Use self-test and temperature-compensation features of the sensors.
***************************************************************************************************************/

/*
  "9DOF Razor IMU" hardware versions: SEN-10125 and SEN-10736

  ATMega328@3.3V, 8MHz

  ADXL345  : Accelerometer
  HMC5843  : Magnetometer on SEN-10125
  HMC5883L : Magnetometer on SEN-10736
  ITG-3200 : Gyro

  Arduino IDE : Select board "Arduino Pro or Pro Mini (3.3v, 8Mhz) w/ATmega328"
*/

/*
  "9DOF Sensor Stick" hardware versions: SEN-10183, SEN-10321 and SEN-10724

  ADXL345  : Accelerometer
  HMC5843  : Magnetometer on SEN-10183 and SEN-10321
  HMC5883L : Magnetometer on SEN-10724
  ITG-3200 : Gyro
*/

/*
  Axis definition (differs from definition printed on the board!):
    X axis pointing forward (towards the short edge with the connector holes)
    Y axis pointing to the right
    and Z axis pointing down.
    
  Positive yaw   : clockwise
  Positive roll  : right wing down
  Positive pitch : nose up
  
  Transformation order: first yaw then pitch then roll.
*/

/*
  Serial commands that the firmware understands:
  
  "#c<params>" - SET _c_alibration parameters. The available options are:
    [a|m|g|c|t] _a_ccelerometer, _m_agnetometer, _g_yro, magnetometerellipsoid_c_enter, magnetometerellipsoid_t_ransform
    [x|y|z] x,y or z 
    [m|M|X|Y|Z] _m_in or _M_ax (accel or magnetometer), X, Y, or Z of transform (magnetometerellipsoid_t_ransform)

  "#p" - PRINT current calibration values

  "#o<params>" - Set OUTPUT mode and parameters. The available options are:
  
      // Streaming output
      "#o0" - DISABLE continuous streaming output. Also see #f below.
      "#o1" - ENABLE continuous streaming output.
      
      // Angles output
      "#ob" - Output angles in BINARY format (yaw/pitch/roll as binary float, so one output frame
              is 3x4 = 12 bytes long).
      "#ot" - Output angles in TEXT format (Output frames have form like "#YPR=-142.28,-5.38,33.52",
              followed by carriage return and line feed [\r\n]).
      "#ox" - Output angles and linear acceleration and rotational
              velocity. Angles are in degrees, acceleration is
              in units of 1.0 = 1/256 G (9.8/256 m/s^2). Rotational
              velocity is in rad/s^2. (Output frames have form like
              "#YPRAG=-142.28,-5.38,33.52,0.1,0.1,1.0,0.01,0.01,0.01",
              followed by carriage return and line feed [\r\n]).
      // Sensor calibration
      "#oc" - Go to CALIBRATION output mode.
      "#on" - When in calibration mode, go on to calibrate NEXT sensor.
      
      // Sensor data output
      "#osct" - Output CALIBRATED SENSOR data of all 9 axes in TEXT format.
                One frame consist of three lines - one for each sensor: acc, mag, gyr.
      "#osrt" - Output RAW SENSOR data of all 9 axes in TEXT format.
                One frame consist of three lines - one for each sensor: acc, mag, gyr.
      "#osbt" - Output BOTH raw and calibrated SENSOR data of all 9 axes in TEXT format.
                One frame consist of six lines - like #osrt and #osct combined (first RAW, then CALIBRATED).
                NOTE: This is a lot of number-to-text conversion work for the little 8MHz chip on the Razor boards.
                In fact it's too much and an output frame rate of 50Hz can not be maintained. #osbb.
      "#oscb" - Output CALIBRATED SENSOR data of all 9 axes in BINARY format.
                One frame consist of three 3x3 float values = 36 bytes. Order is: acc x/y/z, mag x/y/z, gyr x/y/z.
      "#osrb" - Output RAW SENSOR data of all 9 axes in BINARY format.
                One frame consist of three 3x3 float values = 36 bytes. Order is: acc x/y/z, mag x/y/z, gyr x/y/z.
      "#osbb" - Output BOTH raw and calibrated SENSOR data of all 9 axes in BINARY format.
                One frame consist of 2x36 = 72 bytes - like #osrb and #oscb combined (first RAW, then CALIBRATED).
      
      // Error message output        
      "#oe0" - Disable ERROR message output.
      "#oe1" - Enable ERROR message output.
    
    
  "#f" - Request one output frame - useful when continuous output is disabled and updates are
         required in larger intervals only. Though #f only requests one reply, replies are still
         bound to the internal 20ms (50Hz) time raster. So worst case delay that #f can add is 19.99ms.
         
         
  "#s<xy>" - Request synch token - useful to find out where the frame boundaries are in a continuous
         binary stream or to see if tracker is present and answering. The tracker will send
         "#SYNCH<xy>\r\n" in response (so it's possible to read using a readLine() function).
         x and y are two mandatory but arbitrary bytes that can be used to find out which request
         the answer belongs to.
          
          
  ("#C" and "#D" - Reserved for communication with optional Bluetooth module.)
  
  Newline characters are not required. So you could send "#ob#o1#s", which
  would set binary output mode, enable continuous streaming output and request
  a synch token all at once.
  
  The status LED will be on if streaming output is enabled and off otherwise.
  
  Byte order of binary output is little-endian: least significant byte comes first.
*/



/*****************************************************************/
/*********** USER SETUP AREA! Set your options here! *************/
/*****************************************************************/

// HARDWARE OPTIONS
/*****************************************************************/
// Select your hardware here by uncommenting one line!
//#define HW__VERSION_CODE 10125 // SparkFun "9DOF Razor IMU" version "SEN-10125" (HMC5843 magnetometer)
#define HW__VERSION_CODE 10736 // SparkFun "9DOF Razor IMU" version "SEN-10736" (HMC5883L magnetometer)
//#define HW__VERSION_CODE 10183 // SparkFun "9DOF Sensor Stick" version "SEN-10183" (HMC5843 magnetometer)
//#define HW__VERSION_CODE 10321 // SparkFun "9DOF Sensor Stick" version "SEN-10321" (HMC5843 magnetometer)
//#define HW__VERSION_CODE 10724 // SparkFun "9DOF Sensor Stick" version "SEN-10724" (HMC5883L magnetometer)


// OUTPUT OPTIONS
/*****************************************************************/
// Set your serial port baud rate used to send out data here!
#define OUTPUT__BAUD_RATE 57600

// Sensor data output interval in milliseconds
// This may not work, if faster than 20ms (=50Hz)
// Code is tuned for 20ms, so better leave it like that
#define OUTPUT__DATA_INTERVAL 20  // in milliseconds

// Output mode definitions (do not change)
#define OUTPUT__MODE_CALIBRATE_SENSORS 0 // Outputs sensor min/max values as text for manual calibration
#define OUTPUT__MODE_ANGLES 1 // Outputs yaw/pitch/roll in degrees
#define OUTPUT__MODE_SENSORS_CALIB 2 // Outputs calibrated sensor values for all 9 axes
#define OUTPUT__MODE_SENSORS_RAW 3 // Outputs raw (uncalibrated) sensor values for all 9 axes
#define OUTPUT__MODE_SENSORS_BOTH 4 // Outputs calibrated AND raw sensor values for all 9 axes
#define OUTPUT__MODE_ANGLES_AG_SENSORS 5 // Outputs yaw/pitch/roll in degrees + linear accel + rot. vel
// Output format definitions (do not change)
#define OUTPUT__FORMAT_TEXT 0 // Outputs data as text
#define OUTPUT__FORMAT_BINARY 1 // Outputs data as binary float

// Select your startup output mode and format here!
int output_mode = OUTPUT__MODE_ANGLES;
int output_format = OUTPUT__FORMAT_TEXT;

// Select if serial continuous streaming output is enabled per default on startup.
#define OUTPUT__STARTUP_STREAM_ON true  // true or false

// If set true, an error message will be output if we fail to read sensor data.
// Message format: "!ERR: reading <sensor>", followed by "\r\n".
boolean output_errors = false;  // true or false

// Bluetooth
// You can set this to true, if you have a Rovering Networks Bluetooth Module attached.
// The connect/disconnect message prefix of the module has to be set to "#".
// (Refer to manual, it can be set like this: SO,#)
// When using this, streaming output will only be enabled as long as we're connected. That way
// receiver and sender are synchronzed easily just by connecting/disconnecting.
// It is not necessary to set this! It just makes life easier when writing code for
// the receiving side. The Processing test sketch also works without setting this.
// NOTE: When using this, OUTPUT__STARTUP_STREAM_ON has no effect!
#define OUTPUT__HAS_RN_BLUETOOTH false  // true or false


// SENSOR CALIBRATION
/*****************************************************************/
// How to calibrate? Read the tutorial at http://dev.qu.tu-berlin.de/projects/sf-razor-9dof-ahrs
// Put MIN/MAX and OFFSET readings for your board here!
// Accelerometer
// "accel x,y,z (min/max) = X_MIN/X_MAX  Y_MIN/Y_MAX  Z_MIN/Z_MAX"
float ACCEL_X_MIN = -284;
float ACCEL_X_MAX = 272;
float ACCEL_Y_MIN = -272;
float ACCEL_Y_MAX = 280;
float ACCEL_Z_MIN = -200;
float ACCEL_Z_MAX = 266;

// Magnetometer (standard calibration mode)
// "magn x,y,z (min/max) = X_MIN/X_MAX  Y_MIN/Y_MAX  Z_MIN/Z_MAX"
float MAGN_X_MIN = -600;
float MAGN_X_MAX = 600;
float MAGN_Y_MIN = -600;
float MAGN_Y_MAX = 600;
float MAGN_Z_MIN = -600;
float MAGN_Z_MAX = 600;

// Magnetometer (extended calibration mode)
// Set to true to use extended magnetometer calibration (compensates hard & soft iron errors)
boolean CALIBRATION__MAGN_USE_EXTENDED = false;
float magn_ellipsoid_center[3] = {0, 0, 0};
float magn_ellipsoid_transform[3][3] = {{0, 0, 0}, {0, 0, 0}, {0, 0, 0}};

// Gyroscope
// "gyro x,y,z (current/average) = .../OFFSET_X  .../OFFSET_Y  .../OFFSET_Z
float GYRO_AVERAGE_OFFSET_X = 43.7;
float GYRO_AVERAGE_OFFSET_Y = 4.37;
float GYRO_AVERAGE_OFFSET_Z = 13.57;


// DEBUG OPTIONS
/*****************************************************************/
// When set to true, gyro drift correction will not be applied
#define DEBUG__NO_DRIFT_CORRECTION false
// Print elapsed time after each I/O loop
#define DEBUG__PRINT_LOOP_TIME false


/*****************************************************************/
/****************** END OF USER SETUP AREA!  *********************/
/*****************************************************************/










// Check if hardware version code is defined
#ifndef HW__VERSION_CODE
  // Generate compile error
  #error YOU HAVE TO SELECT THE HARDWARE YOU ARE USING! See "HARDWARE OPTIONS" in "USER SETUP AREA" at top of Razor_AHRS.ino!
#endif
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
void loop()
{
  // Read incoming control messages
  if (Serial.available() >= 2)
  {
    if (Serial.read() == '#') // Start of new control message
    {
      int command = Serial.read(); // Commands
      if (command == 'f') // request one output _f_rame
        output_single_on = true;
      else if (command == 's') // _s_ynch request
      {
        // Read ID
        byte id[2];
        id[0] = readChar();
        id[1] = readChar();
        
        // Reply with synch message
        Serial.print("#SYNCH");
        Serial.write(id, 2);
        Serial.println();
      }
      else if (command == 'o') // Set _o_utput mode
      {
        char output_param = readChar();
        if (output_param == 'n')  // Calibrate _n_ext sensor
        {
          curr_calibration_sensor = (curr_calibration_sensor + 1) % 3;
          reset_calibration_session_flag = true;
        }
        else if (output_param == 't') // Output angles as _t_ext
        {
          output_mode = OUTPUT__MODE_ANGLES;
          output_format = OUTPUT__FORMAT_TEXT;
        }
        else if (output_param == 'b') // Output angles in _b_inary format
        {
          output_mode = OUTPUT__MODE_ANGLES;
          output_format = OUTPUT__FORMAT_BINARY;
        }
        else if (output_param == 'c') // Go to _c_alibration mode
        {
          output_mode = OUTPUT__MODE_CALIBRATE_SENSORS;
          reset_calibration_session_flag = true;
        }
        else if (output_param == 'x') // Go to _c_alibration mode for both sensor and angle comment: Tang
        {
          output_mode = OUTPUT__MODE_ANGLES_AG_SENSORS;
          reset_calibration_session_flag = true;
        }
        else if (output_param == 's') // Output _s_ensor values
        {
          char values_param = readChar();
          char format_param = readChar();
          if (values_param == 'r')  // Output _r_aw sensor values
            output_mode = OUTPUT__MODE_SENSORS_RAW;
          else if (values_param == 'c')  // Output _c_alibrated sensor values
            output_mode = OUTPUT__MODE_SENSORS_CALIB;
          else if (values_param == 'b')  // Output _b_oth sensor values (raw and calibrated)
            output_mode = OUTPUT__MODE_SENSORS_BOTH;

          if (format_param == 't') // Output values as _t_text
            output_format = OUTPUT__FORMAT_TEXT;
          else if (format_param == 'b') // Output values in _b_inary format
            output_format = OUTPUT__FORMAT_BINARY;
        }
        else if (output_param == '0') // Disable continuous streaming output
        {
          turn_output_stream_off();
          reset_calibration_session_flag = true;
        }
        else if (output_param == '1') // Enable continuous streaming output
        {
          reset_calibration_session_flag = true;
          turn_output_stream_on();
        }
        else if (output_param == 'e') // _e_rror output settings
        {
          char error_param = readChar();
          if (error_param == '0') output_errors = false;
          else if (error_param == '1') output_errors = true;
          else if (error_param == 'c') // get error count
          {
            Serial.print("#AMG-ERR:");
            Serial.print(num_accel_errors); Serial.print(",");
            Serial.print(num_magn_errors); Serial.print(",");
            Serial.println(num_gyro_errors);
          }
        }
      }
      else if (command == 'p') // Set _p_rint calibration values
      {
         Serial.print("ACCEL_X_MIN:");Serial.println(ACCEL_X_MIN);
         Serial.print("ACCEL_X_MAX:");Serial.println(ACCEL_X_MAX);
         Serial.print("ACCEL_Y_MIN:");Serial.println(ACCEL_Y_MIN);
         Serial.print("ACCEL_Y_MAX:");Serial.println(ACCEL_Y_MAX);
         Serial.print("ACCEL_Z_MIN:");Serial.println(ACCEL_Z_MIN);
         Serial.print("ACCEL_Z_MAX:");Serial.println(ACCEL_Z_MAX);
         Serial.println(""); 
         Serial.print("MAGN_X_MIN:");Serial.println(MAGN_X_MIN);
         Serial.print("MAGN_X_MAX:");Serial.println(MAGN_X_MAX);
         Serial.print("MAGN_Y_MIN:");Serial.println(MAGN_Y_MIN);
         Serial.print("MAGN_Y_MAX:");Serial.println(MAGN_Y_MAX);
         Serial.print("MAGN_Z_MIN:");Serial.println(MAGN_Z_MIN);
         Serial.print("MAGN_Z_MAX:");Serial.println(MAGN_Z_MAX);
         Serial.println("");
         Serial.print("MAGN_USE_EXTENDED:");
         if (CALIBRATION__MAGN_USE_EXTENDED) 
           Serial.println("true");
         else
           Serial.println("false");
         Serial.print("magn_ellipsoid_center:[");Serial.print(magn_ellipsoid_center[0],4);Serial.print(",");
         Serial.print(magn_ellipsoid_center[1],4);Serial.print(",");
         Serial.print(magn_ellipsoid_center[2],4);Serial.println("]");
         Serial.print("magn_ellipsoid_transform:[");
         for(int i = 0; i < 3; i++){
           Serial.print("[");
           for(int j = 0; j < 3; j++){
             Serial.print(magn_ellipsoid_transform[i][j],7);
             if (j < 2) Serial.print(",");
           }
           Serial.print("]");
           if (i < 2) Serial.print(",");
         }
         Serial.println("]");
         Serial.println(""); 
         Serial.print("GYRO_AVERAGE_OFFSET_X:");Serial.println(GYRO_AVERAGE_OFFSET_X);
         Serial.print("GYRO_AVERAGE_OFFSET_Y:");Serial.println(GYRO_AVERAGE_OFFSET_Y);
         Serial.print("GYRO_AVERAGE_OFFSET_Z:");Serial.println(GYRO_AVERAGE_OFFSET_Z);
      }
      else if (command == 'c') // Set _i_nput mode
      {
        char input_param = readChar();
        if (input_param == 'a')  // Calibrate _a_ccelerometer
        {
          char axis_param = readChar();
          char type_param = readChar();
          float value_param = Serial.parseFloat();
          if (axis_param == 'x')  // x value
          {
            if (type_param == 'm')
              ACCEL_X_MIN = value_param;
            else if (type_param == 'M')
              ACCEL_X_MAX = value_param;
          }
          else if (axis_param == 'y')  // y value
          {
            if (type_param == 'm')
              ACCEL_Y_MIN = value_param;
            else if (type_param == 'M')
              ACCEL_Y_MAX = value_param;
          }
          else if (axis_param == 'z')  // z value
          {
            if (type_param == 'm')
              ACCEL_Z_MIN = value_param;
            else if (type_param == 'M')
              ACCEL_Z_MAX = value_param;
          }
          recalculateAccelCalibration();
        }
        else if (input_param == 'm')  // Calibrate _m_agnetometer (basic)
        {
          //disable extended magnetometer calibration
          CALIBRATION__MAGN_USE_EXTENDED = false;
          char axis_param = readChar();
          char type_param = readChar();
          float value_param = Serial.parseFloat();
          if (axis_param == 'x')  // x value
          {
            if (type_param == 'm')
              MAGN_X_MIN = value_param;
            else if (type_param == 'M')
              MAGN_X_MAX = value_param;
          }
          else if (axis_param == 'y')  // y value
          {
            if (type_param == 'm')
              MAGN_Y_MIN = value_param;
            else if (type_param == 'M')
              MAGN_Y_MAX = value_param;
          }
          else if (axis_param == 'z')  // z value
          {
            if (type_param == 'm')
              MAGN_Z_MIN = value_param;
            else if (type_param == 'M')
              MAGN_Z_MAX = value_param;
          }
          recalculateMagnCalibration();
        }
        else if (input_param == 'c')  // Calibrate magnetometerellipsoid_c_enter (extended)
        {
          //enable extended magnetometer calibration
          CALIBRATION__MAGN_USE_EXTENDED = true;
          char axis_param = readChar();
          float value_param = Serial.parseFloat();
          if (axis_param == 'x')  // x value
              magn_ellipsoid_center[0] = value_param;
          else if (axis_param == 'y')  // y value
              magn_ellipsoid_center[1] = value_param;
          else if (axis_param == 'z')  // z value
              magn_ellipsoid_center[2] = value_param;
        }
        else if (input_param == 't')  // Calibrate magnetometerellipsoid_t_ransform (extended)
        {
          //enable extended magnetometer calibration
          CALIBRATION__MAGN_USE_EXTENDED = true;
          char axis_param = readChar();
          char type_param = readChar();
          float value_param = Serial.parseFloat();
          if (axis_param == 'x')  // x value
          {
            if (type_param == 'X')
              magn_ellipsoid_transform[0][0] = value_param;
            else if (type_param == 'Y')
              magn_ellipsoid_transform[0][1] = value_param;
            else if (type_param == 'Z')
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

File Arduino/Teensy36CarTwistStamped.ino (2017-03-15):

/*
  Arduino ROS node for JetsonCar project
  The Arduino controls a TRAXXAS Rally Car
  MIT License
  JetsonHacks (2016)
*/

/*
Modified by Daniel Tobias
Runs on a Teensy 3.6 
Runs a Traxxas Rally 2WD
ESC Tied to pin(10) 
Steering Servo tied to pin(9)
Runs everything using floating point cause Teensy 3.6 has Hardware Floating Point Unit (FPU)
Changed PWM write to writeMicroseconds for precision
Added a smoothing function to throttle to handle stray pulses and behave more like a car
Added Turn Signal LEDs
Kill switch signal from RF reciever tied to pin(38)
Added break/reverse signal on twist.linear.z ESC takes first signal below 1500 microseconds as breaks and second sequential signal as reverse
Changed message from Twist to TwistStamped for recording synchronization 
Pin Out for Teensy 3.6 is in link below
https://forum.pjrc.com/attachment.php?attachmentid=8071&d=1473211335

*/

#if defined(ARDUINO) && ARDUINO >= 100
#include "Arduino.h"
#else
#include <WProgram.h>
#endif

#include <Servo.h>
#define USB_USBCON
#include <ros.h>
#include <std_msgs/UInt16.h>
#include <std_msgs/String.h>
#include <std_msgs/Int32.h>
#include <std_msgs/Empty.h>
#include <geometry_msgs/Twist.h>
#include <geometry_msgs/TwistStamped.h>

ros::NodeHandle  nodeHandle;
// These are general bounds for the steering servo and the
// TRAXXAS Electronic Speed Controller (ESC)
const float minSteering = 1200 ;
const float maxSteering = 1800 ;
const float minThrottle = 0 ;
const float maxThrottle = 1680 ;
const float steeringIncrement = 9.0;
  float escCommand;
  float escThrottle;
  float smoothSteering = 1500;
  float diffGreat;
  float diffLess;

Servo steeringServo;
Servo electronicSpeedController ;  // The ESC on the TRAXXAS works like a Servo

std_msgs::Int32 str_msg;
ros::Publisher chatter("chatter", &str_msg);

// Arduino 'map' funtion for floating point
float fmap (float toMap, float in_min, float in_max, float out_min, float out_max) {
  return (toMap - in_min) * (out_max - out_min) / (in_max - in_min) + out_min;
}

void driveCallback ( const geometry_msgs::TwistStamped&  twistMsg )
{

  float steeringAngle = fmap(twistMsg.twist.angular.z, 0.0, 1.0, minSteering, maxSteering) ;
  // The following could be useful for debugging
   //str_msg.data= steeringAngle ;
  // Check to make sure steeringAngle is within car range
  if (steeringAngle < minSteering) {
    steeringAngle = minSteering;
  }
  if (steeringAngle > maxSteering) {
    
    steeringAngle = maxSteering ;
  }

//   float diff = steeringAngle - smoothSteering;     //Future smoothing for steering
//   if (diff >= steeringIncrement){                  //currently solved with 60Hz refresh on callbacks from node
//    smoothSteering += steeringIncrement;            
//   }
//   else if (diff <= -steeringIncrement) {
//    smoothSteering -= steeringIncrement;
//   }
//   else {
//    smoothSteering = steeringAngle;
//   }
   
  steeringServo.writeMicroseconds(steeringAngle) ;
  if(steeringAngle < 1450)
    digitalWrite(29, HIGH - digitalRead(29));  //blinks LED if turning left
  else if(steeringAngle> 1550)
    digitalWrite(30, HIGH - digitalRead(30));  //blinds LED if turning right
  else {
    digitalWrite(30,LOW);
    digitalWrite(29,LOW);
  }

  // ESC forward is between 0.5 and 1.0

  if (twistMsg.twist.linear.x >= 0.5) {
    escCommand = (float)fmap(twistMsg.twist.linear.x, 0.5, 1.0, 1500.0, maxThrottle) ;
  } else {
    //escCommand = (int)fmap(twistMsg.twist.linear.x, 0.0, 1.0, 0.0, 1780.0) ;
    escCommand = (float)fmap(twistMsg.twist.linear.x, 0.0, 0.5, 0.0, 1500.0) ;
  }
  // Check to make sure throttle command is within bounds
  if (escCommand < minThrottle) {
    escCommand = minThrottle;
  }
  if (escCommand > maxThrottle) {
    escCommand = maxThrottle ;
  }
  // The following could be useful for debugging
   //str_msg.data= escCommand ;
   //chatter.publish(&str_msg);
    if(digitalRead(38)){          //reads signal from RF Reciever. Will set throttle to neutral if signal is high
       delay(5);
       if(digitalRead(38)){
       electronicSpeedController.writeMicroseconds(1500) ;
       }
    }
    else if(twistMsg.twist.linear.z == 1.0) {
      electronicSpeedController.writeMicroseconds(1400); //brakes
    }
    else{
      escThrottle = escThrottle + 0.05*(escCommand-escThrottle);   //Exponential Smoothing ( ͡° ͜ʖ ͡°) for throttle
      electronicSpeedController.writeMicroseconds(escThrottle) ;
      digitalWrite(13, HIGH - digitalRead(13)); //toggle led
    }


  
}

ros::Subscriber<geometry_msgs::TwistStamped> driveSubscriber("/cmd_vel", &driveCallback) ;

void setup() {
  pinMode(38, INPUT);
  pinMode(30, OUTPUT);
  pinMode(29, OUTPUT);
  pinMode(13, OUTPUT);
  Serial.begin(57600) ;
  nodeHandle.initNode();
  // This can be useful for debugging purposes
  nodeHandle.advertise(chatter);
  // Subscribe to the steering and throttle messages
  nodeHandle.subscribe(driveSubscriber) ;
  // Attach the servos to actual pins
  steeringServo.attach(9); // Steering servo is attached to pin 9
  electronicSpeedController.attach(10); // ESC is on pin 10
  // Initialize Steering and ESC setting
  // Steering centered is 90, throttle at neutral is 90
  steeringServo.writeMicroseconds(1500) ;
                                     
  //digitalWrite(13, HIGH - digitalRead(13));    
  //electronicSpeedController.writeMicroseconds(1700);   //ESC Activation sequence
  //delay(1000);
  //electronicSpeedController.writeMicroseconds(1300);
  //delay(1000);
  //electronicSpeedController.writeMicroseconds(1500);
  //delay(1000);
  
}

void loop() 
{
  nodeHandle.spinOnce();      //refreshes nodes
  delay(1);
}

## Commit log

2016-11-20 Create Razor_AHRS.ino
    calibrated
2016-11-20 Create drivingMsecondsFLOAT
    modified from Jetsonhacks
2017-02-01 Add files via upload
    imu node disabled in launch
2017-02-05 added sample trained model
2017-02-08 added bom
2017-02-20 added reinforced realsense holder
    [new camera head.SLDPRT, new camera head.STL]
2017-02-21 still working on this picture
    but laptop battery died
2017-02-21 added reinforced mount to readme
2017-02-21 added initial prototype
2017-03-10 add schematics
2017-03-15 changed to correct topic name
    [Teensy36CarTwistStamped.ino]
2017-03-19 renamed and added main and top panels
    [car_RealSenseR200_mount.SLDPRT, car_RealSenseR200_mount.STL, car_front_headlights.SLDPRT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]
2017-03-27 inline to circuit designs
2017-03-28 added USB holes for standoffs
2017-03-28 changed hole dimensioning to coordinate system
